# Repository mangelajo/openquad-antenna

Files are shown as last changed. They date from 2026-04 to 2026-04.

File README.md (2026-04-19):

# OpenQuad — Modular Cubical Quad antenna by EA4IPW

Modular and foldable cubical quad antenna design for any HF/VHF/UHF band, built with 3D-printed parts, fiberglass spreaders and an aluminum boom.

<p align="center">
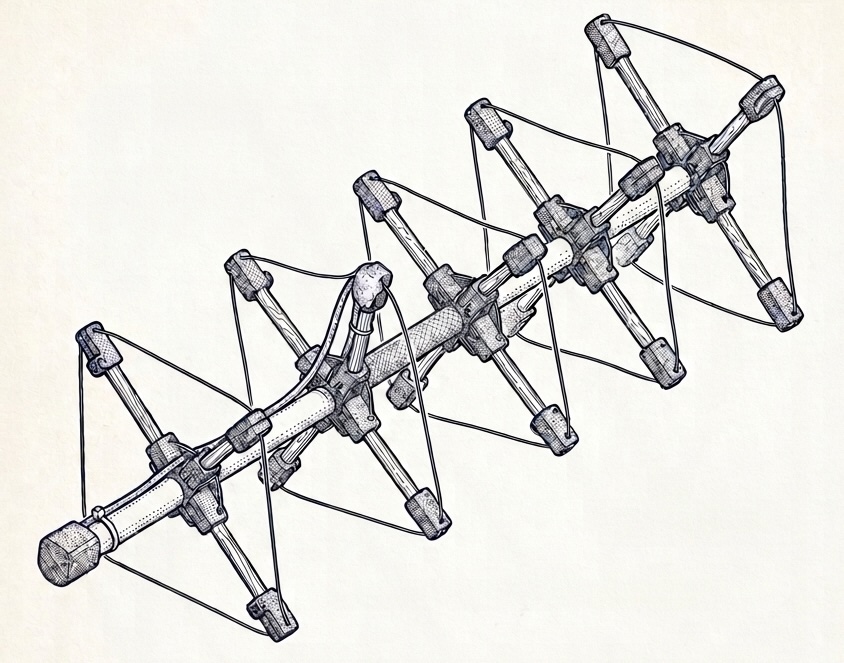
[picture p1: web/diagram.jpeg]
OpenQuad design diagram
  
</p>

## 📖 Construction guide / Guía de construcción

| Language | Build guide | Theory & formulas |
|---|---|---|
| 🇪🇸 Español | [README.es.md](docs/README.es.md) | [TEORIA.es.md](docs/TEORIA.es.md) |
| 🇬🇧 English | [README.en.md](docs/README.en.md) | [TEORIA.en.md](docs/TEORIA.en.md) |
| 🇮🇹 Italiano | [README.it.md](docs/README.it.md) | [TEORIA.it.md](docs/TEORIA.it.md) |
| 🇵🇹 Português | [README.pt.md](docs/README.pt.md) | [TEORIA.pt.md](docs/TEORIA.pt.md) |
| 🇯🇵 日本語 | [README.ja.md](docs/README.ja.md) | [TEORIA.ja.md](docs/TEORIA.ja.md) |
| 🇨🇳 中文 | [README.zh.md](docs/README.zh.md) | [TEORIA.zh.md](docs/TEORIA.zh.md) |

## 🧮 Online calculator

Interactive calculator (6 languages) for sizing the elements, calibrating the velocity factor of your wire, and computing the cut/adjustment needed per element after measuring resonance:

**→ [openquad calculator](web/index.html)** (deployed via GitHub Pages)

## 📁 Repository layout

- [src/](src/) — OpenSCAD parametric models for the 3D-printed clamps and hubs
- [stls/](stls/) — Pre-generated STL files ready to print
- [web/](web/) — HTML/JS calculator (deployed to GitHub Pages)
- `*.md` — Build guide and theory documents in 6 languages

---

*73 de EA4IPW — OpenQuad v1.0*

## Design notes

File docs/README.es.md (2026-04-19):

# OpenQuad — Antena Cubical Quad modular y plegable

**Por EA4IPW — Caso práctico: construcción de un quad de 5 elementos para 435 MHz**

<p align="center">
  Diagrama del diseño
</p>

---

## 1. Qué es este diseño

Este proyecto documenta un **diseño de antena Cubical Quad modular y plegable** pensado para fabricarse con piezas impresas en 3D, varillas de fibra de vidrio o madera como spreaders y un boom de PVC, madera o aluminio.

Las características principales del diseño son:

- **Modular:** cada elemento (reflector, driven, directores) se monta sobre un *bloque* independiente que se desliza y se fija al boom. Puedes construir la antena con 2, 3, 5 , 6, 7 .. elementos usando el mismo hardware.
- **Plegable:** los spreaders pivotan sobre el bloque, de modo que la antena puede recogerse para transporte o almacenamiento y desplegarse en segundos para operar.
- **Escalable por banda:** el diseño paramétrico en OpenSCAD ([src/all_in_one.scad](../src/all_in_one.scad)) permite ajustar el diámetro del boom y de los spreaders y regenerar la pieza para otros tamaños de boom y spreader.

- **Ajustable:** los loops se sujetan con abrazaderas impresas ([stls/regular_wire_clamp.stl](../stls/regular_wire_clamp.stl)) que permiten recortar y volver a fijar el cable durante el tuning.

Esta guía documenta el proceso práctico de construcción y ajuste paso a paso. Los fundamentos teóricos (origen de las fórmulas 1005/1030/975, efecto del velocity factor, rendimiento esperado, referencias bibliográficas) se tratan en un documento separado:

> 📘 **[TEORIA.es.md](TEORIA.es.md) — Fundamentos teóricos y referencias**

Las fórmulas son válidas para cualquier frecuencia; como ejemplo práctico detallado se documenta una construcción real para la banda de 70 cm (435 MHz) con cable de instalación PVC de 0.5 mm².

<p align="center">
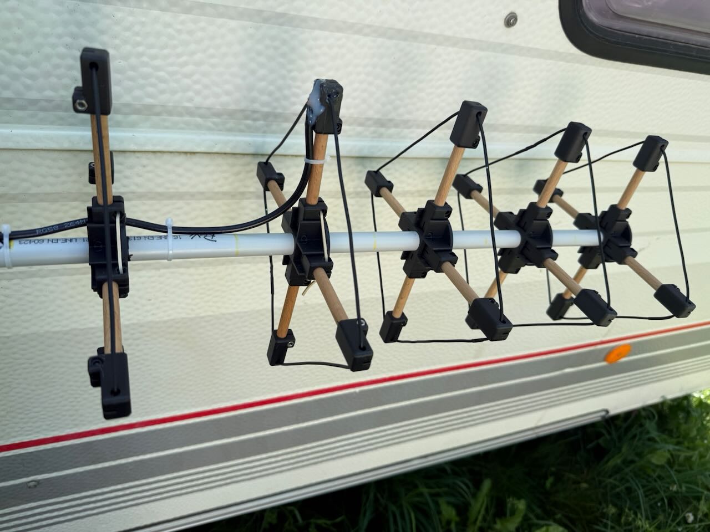
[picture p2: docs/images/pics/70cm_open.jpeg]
Antena desplegada (5 elementos, 435 MHz)
  
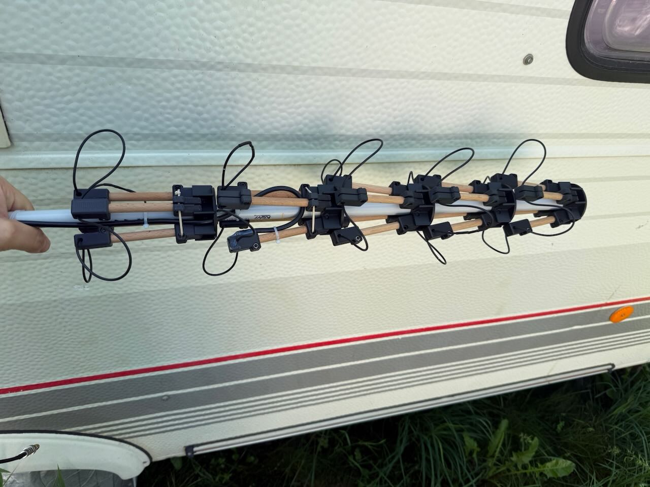
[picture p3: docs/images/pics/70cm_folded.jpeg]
Antena plegada para transporte
  
</p>

---

## 2. Dimensiones para la construcción de referencia (435 MHz, Vf = 0.91)

Las siguientes dimensiones corresponden a la construcción real documentada en esta guía, usando cable PVC de 0.5 mm² con velocity factor medido de 0.91.

> Si construyes para otra frecuencia o con otro tipo de cable, consulta las fórmulas generales y el procedimiento para medir el Vf en [TEORIA.es.md § 2–3](TEORIA.es.md), o usa la [🧮 calculadora online](https://openquad-calc.ea4ipw.es) para obtener las dimensiones directamente.

**Elementos:**

| Elemento | Perímetro (mm) | Perímetro (in) | Lado (mm) | Lado (in) | Spreader (mm) | Spreader (in) |
|---|---|---|---|---|---|---|
| Reflector | 656.8 | 25.86 | 164.2 | 6.46 | 116.1 | 4.57 |
| Driven | 640.8 | 25.23 | 160.2 | 6.31 | 113.3 | 4.46 |
| Director 1 | 621.7 | 24.47 | 155.4 | 6.12 | 109.9 | 4.33 |
| Director 2 | 603.0 | 23.74 | 150.8 | 5.93 | 106.6 | 4.20 |
| Director 3 | 584.9 | 23.03 | 146.2 | 5.76 | 103.4 | 4.07 |
| Director 4 | 567.4 | 22.34 | 141.8 | 5.58 | 100.3 | 3.95 |
| Director 5 | 550.4 | 21.67 | 137.6 | 5.42 | 97.3 | 3.83 |

**Espaciados:**

| Tramo | Distancia (mm) | Distancia (in) |
|---|---|---|
| Reflector → Driven | 137.9 | 5.43 |
| Driven → Director 1 | 103.4 | 4.07 |
| Director → Director | 103.4 | 4.07 |

**Longitud total del boom según configuración:**

| Configuración | Boom (mm) | Boom (in) |
|---|---|---|
| 2 elem (R + DE) | 137.9 | 5.43 |
| 3 elem (R + DE + D1) | 241.4 | 9.50 |
| 4 elem (R + DE + D1 + D2) | 344.8 | 13.57 |
| 5 elem (R + DE + D1–D3) | 448.3 | 17.65 |
| 6 elem (R + DE + D1–D4) | 551.7 | 21.72 |
| 7 elem (R + DE + D1–D5) | 655.2 | 25.80 |

---

## 3. Materiales

Resumen de lo que necesitas para construir la antena. Las secciones siguientes detallan alternativas, dimensionado y justificaciones.

| Material | Especificación recomendada | Cantidad | Subsección |
|---|---|---|---|
| Cable de cobre (elementos) | PVC 0.5 mm² (VHF/UHF); 1–2 mm Ø desnudo o aislado (HF) | Según perímetros (§2) | [3.1](#31-cable-para-los-elementos) |
| Boom | Tubo de aluminio, PVC o madera (cuadrado o circular) | 1, longitud según configuración (§2) | [3.2](#32-boom) |
| Spreaders | Varilla no conductora (fibra de vidrio, haya o PVC), 4–8 mm Ø en VHF/UHF | 4 por elemento | [3.3](#33-spreaders) |
| Tornillos Allen M3 × 12 mm | Hex socket cap (M3×8/M3×10 para spreaders más finos) | 4 por elemento | [3.4](#34-tornillería-y-retención) |
| Tuercas M3 | Hexagonales estándar | 4 por elemento | [3.4](#34-tornillería-y-retención) |
| Goma elástica | Cualquiera que abrace el bloque plegado | 1 por elemento | [3.4](#34-tornillería-y-retención) |
| Coaxial + conector | Según tu equipo (típicamente RG-58/RG-316 en UHF) | 1 | — |
| Termorretráctil | Varios diámetros para aislar soldaduras del feedpoint y empalmes | Unos cm | — |
| Ferritas snap-on mix 43 (opcional, ajuste) | Fair-Rite 0443164251/0443167251 según Ø del coaxial | 5–6 | [4.2](#42-choke-balun-opcional-pero-recomendado-para-la-medida) |

### 3.1. Cable para los elementos

Cualquier cable de cobre con o sin aislamiento sirve. Para cable aislado (PVC, polietileno), recuerda aplicar la corrección de Vf (ver [TEORIA.es.md § 2](TEORIA.es.md)).

En VHF/UHF, secciones de 0.5 mm² a 1.5 mm² funcionan bien. El cable más fino es más manejable; el más grueso mantiene mejor la forma, mi recomendación es el de 0.5mm². A 435 MHz el skin depth es de solo 3 µm, así que toda la corriente fluye por la superficie del conductor. La diferencia de pérdidas entre 0.5 mm² y 1.5 mm² es de ~0.025 dB — completamente despreciable. El ancho de banda se reduce ~8% con el cable más fino, lo que tampoco es significativo en la práctica.

En HF, donde los elementos son mucho más grandes, se usa típicamente cable de cobre de 1–2 mm de diámetro (desnudo o aislado), o incluso cable multifilar para reducir peso.

Para potencias de hasta 50W no hay ningún problema con cable fino. El límite práctico lo ponen las soldaduras y el aislamiento (el PVC se ablanda a ~70°C), no el conductor.

Al unir tramos o cerrar un loop, pela unos 10 mm de cada extremo, únelos en paralelo (trenzando o con un empalme Western Union), suelda con aporte generoso y protege la unión con termorretráctil.

<p align="center">
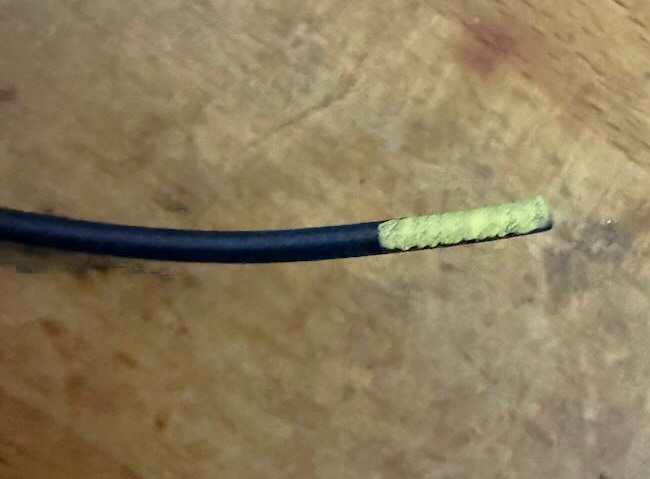
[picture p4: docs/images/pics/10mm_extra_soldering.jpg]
10 mm de cable pelado antes de soldar
  
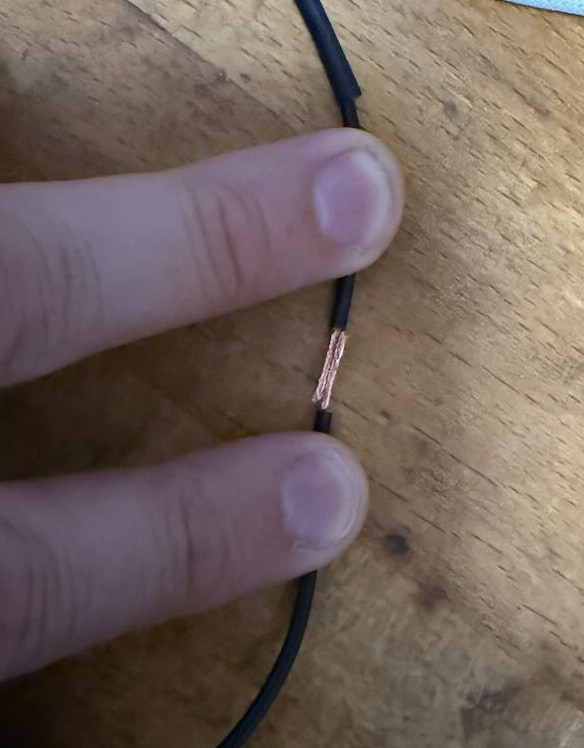
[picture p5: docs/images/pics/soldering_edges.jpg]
Empalme de los dos extremos antes de la soldadura
  
</p>
<p align="center">
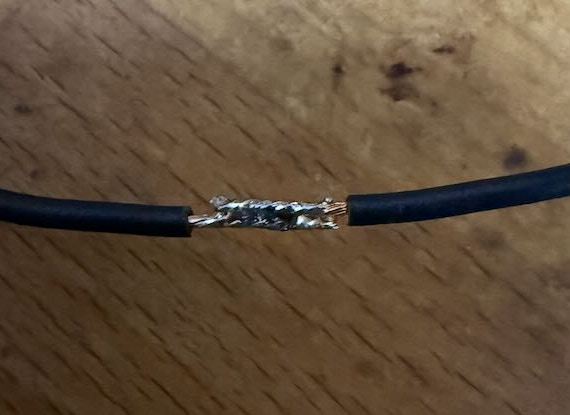
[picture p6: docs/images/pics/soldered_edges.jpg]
Empalme soldado
  
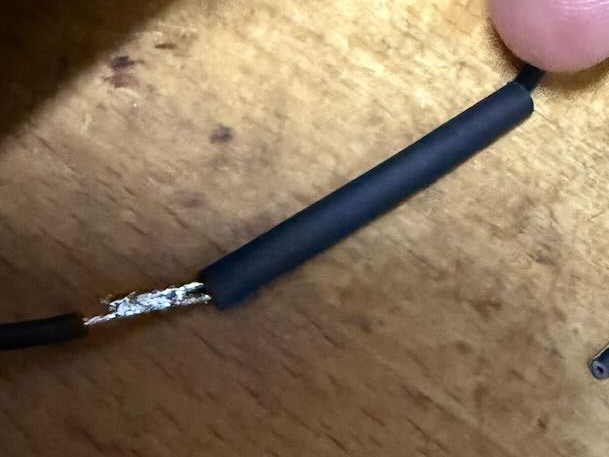
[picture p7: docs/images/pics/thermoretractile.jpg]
Termorretráctil aplicado sobre la soldadura
  
</p>

### 3.2. Boom

El aluminio es ideal: ligero, rígido y fácil de trabajar. Un tubo cuadrado o circular de sección apropiada al tamaño de la antena es suficiente. Para UHF un tubo de PVC también sirve perfectamente.

**¿Afecta un boom metálico a la antena?** En un quad, a diferencia de un Yagi, el boom es perpendicular al plano de los loops y los elementos están separados del boom por los spreaders. El efecto es mínimo o inexistente. **No se necesita corrección de boom** como en un Yagi.

Un boom de madera funciona igual pero es más pesado y absorbe humedad. Su efecto dieléctrico (εr ≈ 2) podría desplazar la frecuencia ~0.1% — irrelevante en la práctica.

Si el boom es circular en vez de cuadrado, no hay diferencia eléctrica. La única consideración es mecánica: asegurar que los hubs de los spreaders queden fijados en la misma orientación angular (ver sección 3.5).

<p align="center">
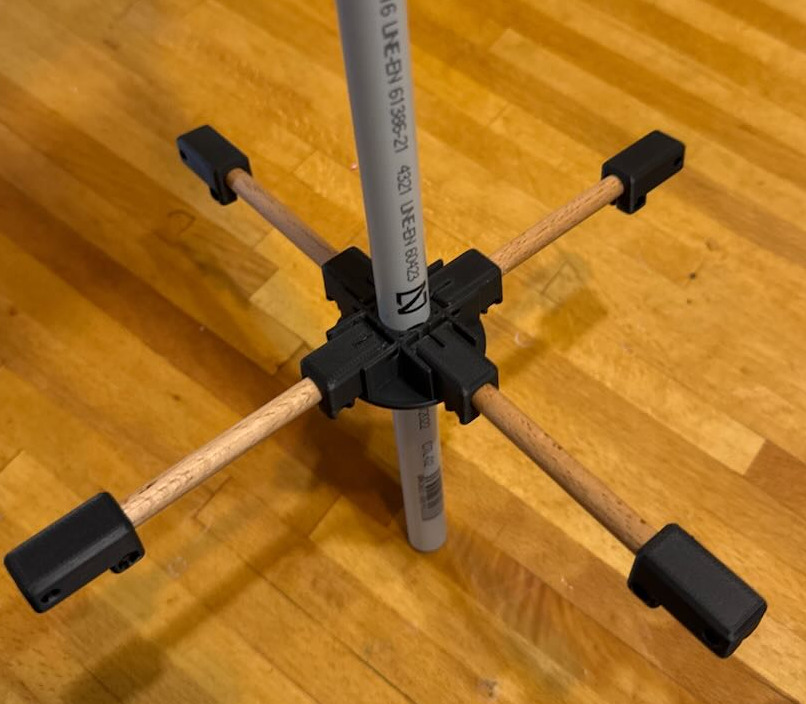
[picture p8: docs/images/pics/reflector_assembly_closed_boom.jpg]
Elemento montado sobre boom de PVC
  
</p>

### 3.3. Spreaders

Varillas de fibra de vidrio, haya, o PVC. Deben ser de material no conductor. El diámetro apropiado depende de la banda: en VHF/UHF, varillas de 4–8 mm son suficientes

<p align="center">
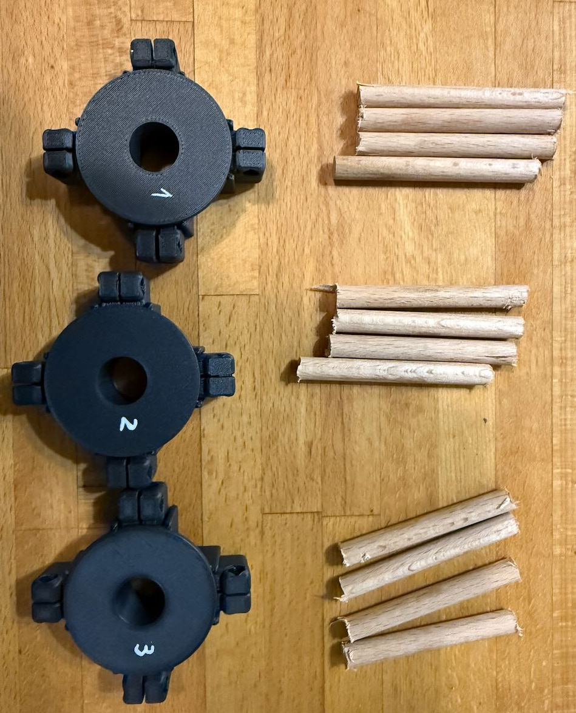
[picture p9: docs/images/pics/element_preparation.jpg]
Hubs impresos y varillas de spreader cortadas a medida
  
</p>

### 3.4. Tornillería y retención

Cada elemento necesita una pequeña cantidad de tornillería estándar para cerrar las abrazaderas sobre los spreaders y mantener el bloque print-in-place plegado durante el transporte:

- **Tornillos Allen (hex socket cap) M3 × 12 mm — 4 por elemento.** Uno por cada abrazadera de spreader; aprietan las dos mitades de la abrazadera alrededor de la varilla. La longitud de 12 mm está dimensionada para un **spreader de 8 mm** — spreaders más finos (4–6 mm) usan un cuerpo de abrazadera más delgado y pueden necesitar un tornillo más corto (M3×8 o M3×10); comprueba la profundidad del canal del tornillo en la pieza renderizada antes de comprar. El alojamiento de la tuerca y la holgura del tornillo están dimensionados para M3 en [src/antenna_spreader_clamp.scad](../src/antenna_spreader_clamp.scad).
- **Tuercas M3 — 4 por elemento.** Se asientan en el hueco hexagonal de cada abrazadera antes de apretar el tornillo.
- **Goma elástica — 1 por elemento.** Envuelve el bloque `all_in_one` plegado para mantener las cuatro abrazaderas cerradas contra el collar del boom durante transporte y almacenamiento.

<p align="center">
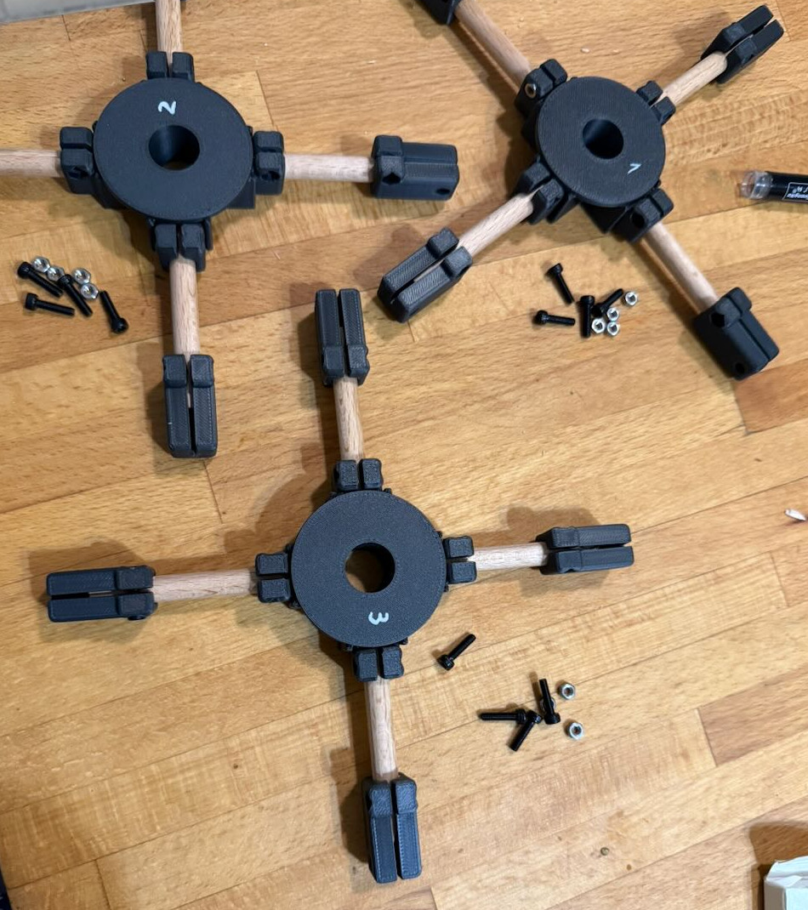
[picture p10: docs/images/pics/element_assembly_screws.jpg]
Bloques montados con tornillería M3
  
</p>

### 3.5. Alineación de los elementos

Todos los loops cuadrados deben estar **alineados en la misma orientación rotacional** sobre el boom. Si se rota un elemento respecto a los demás, el acoplamiento entre elementos se degrada porque los segmentos de corriente dejan de ser paralelos.

- **Unos pocos grados de error:** efecto despreciable.
- **45° de rotación:** acoplamiento seriamente degradado, pérdida de ganancia y F/B.

Con boom cuadrado la alineación es natural. Con boom circular, asegura la orientación con un tornillo prisionero, un pin pasante, o una gota de pegamento.

<p align="center">
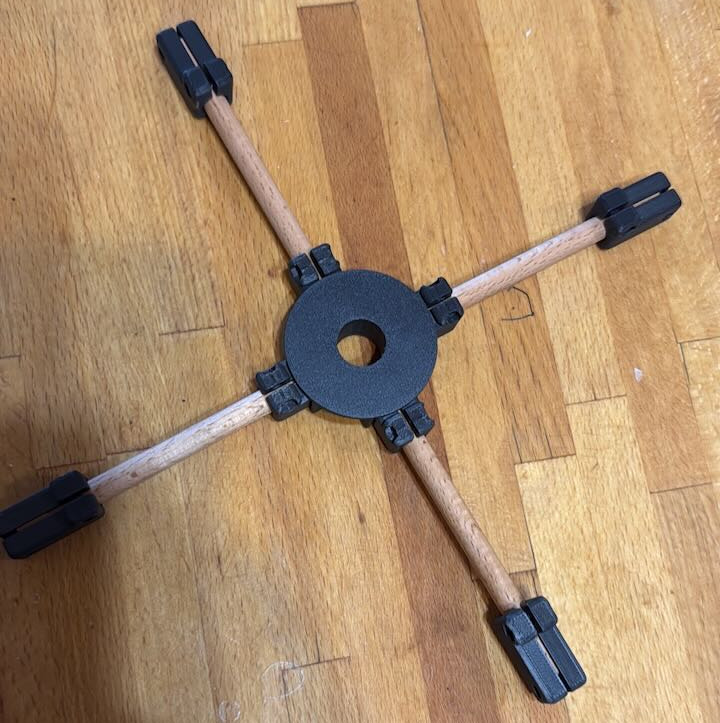
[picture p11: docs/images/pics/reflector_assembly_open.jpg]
Elemento desplegado (spreaders abiertos en X)
  
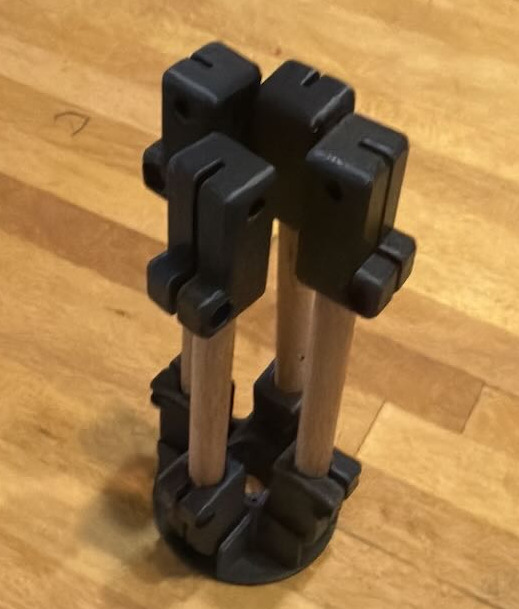
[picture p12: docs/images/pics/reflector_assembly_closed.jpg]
Elemento plegado (spreaders cerrados)
  
</p>

---

## 4. Ajuste paso a paso

### 4.1. Herramientas necesarias

- Analizador de antenas (NanoVNA, LiteVNA, o similar)
- Cable coaxial corto con conector para el VNA
- Soldador y estaño
- Regla milimetrada o calibre digital
- Alicates de corte fino

<p align="center">
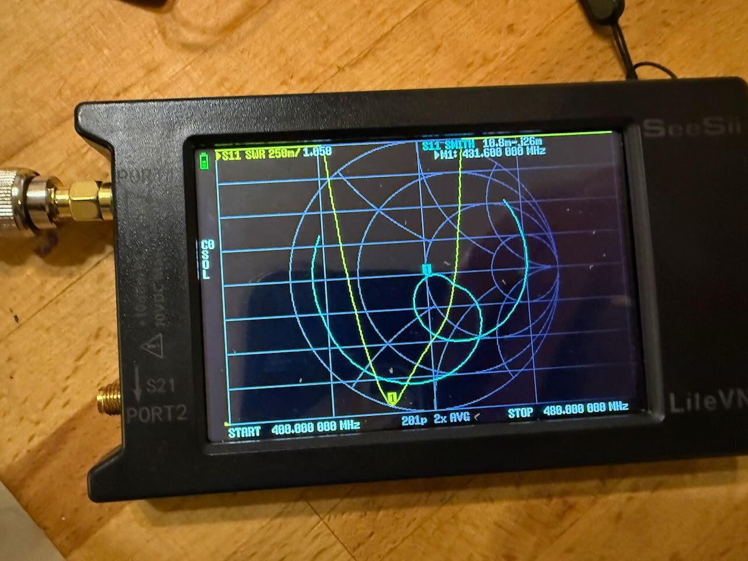
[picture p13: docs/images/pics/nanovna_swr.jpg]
NanoVNA mostrando carta de Smith y SWR de la antena
  
</p>

### 4.2. Choke balun (opcional pero recomendado para la medida)

Un choke balun en el feedpoint mejora la fiabilidad de las medidas al impedir que la trenza del coaxial radie y altere los resultados. Sin choke, tocar o mover el cable del VNA puede cambiar las lecturas.

**Para HF:** un choke bobinado clásico funciona bien: 6–10 vueltas de coaxial sobre un toroide de ferrita (FT-140-43 o similar).

**Para VHF/UHF:** NO uses un choke bobinado — a frecuencias altas la capacitancia entre espiras crea resonancias parásitas. En su lugar, usa **ferritas snap-on (clamp-on)** de mix 43 ensartadas en línea sobre el coaxial justo detrás del feedpoint. 5–6 unidades proporcionan impedancia suficiente.

Referencia de ferritas snap-on válidas para VHF/UHF: Fair-Rite 0443164251 (cable ≤6.6 mm), Fair-Rite 0443167251 (cable ≤9.85 mm), o Fair-Rite 0443164151 (cable ≤12.7 mm), todas en material mix 43. Disponibles en Mouser, DigiKey, o distribuidores similares.

Las snap-on se abren y cierran con los dedos, no requieren herramientas, y son completamente reutilizables.

**Nota:** Muchas antenas comerciales de tipo quad no llevan choke y funcionan perfectamente. El quad tiene una geometría intrínsecamente bien equilibrada en el feedpoint. El choke es principalmente para obtener medidas fiables durante el ajuste, no un requisito para el uso normal.

<p align="center">
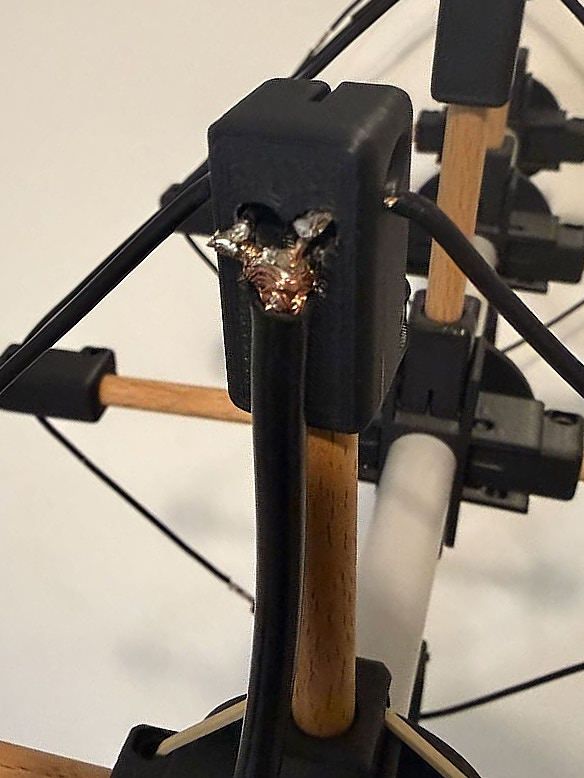
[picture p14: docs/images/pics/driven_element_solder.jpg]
Detalle de la soldadura del driven
  
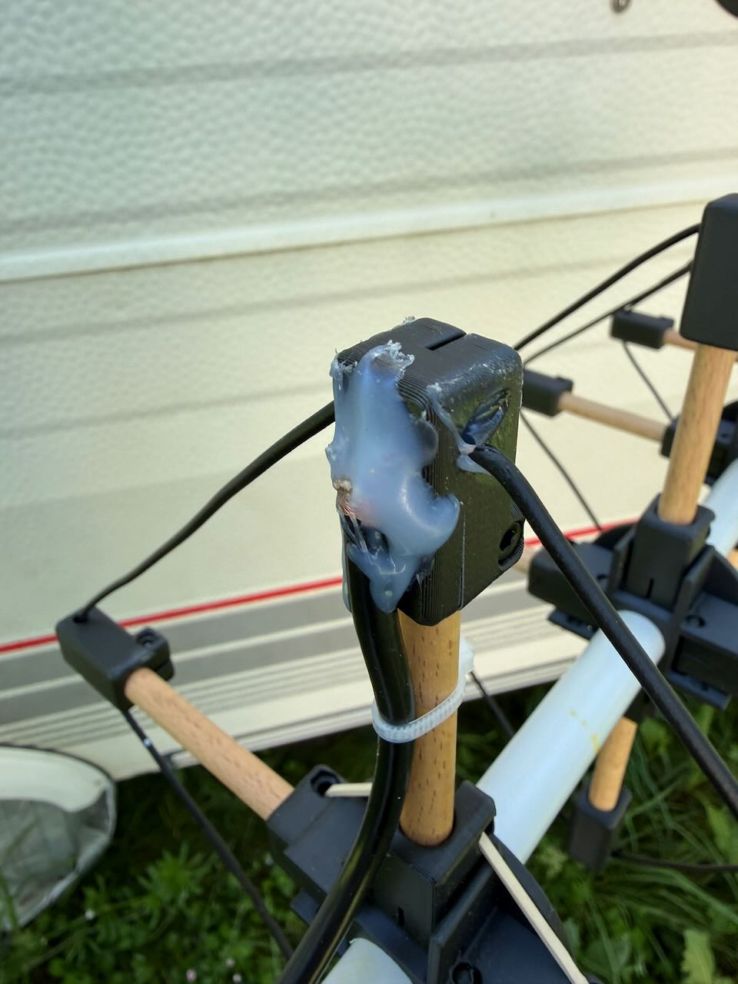
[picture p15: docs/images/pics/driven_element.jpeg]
Driven element con coaxial y sellado
  
</p>

### 4.3. Procedimiento de ajuste

#### Paso 1 — Construir y calibrar el Vf

Todo cable real tiene Vf < 1. El cobre desnudo al aire está alrededor de 0.97 y 0.99, los cables aislados bajan a 0.90–0.97 según el material. El procedimiento recomendado es partir de un valor aproximado y calibrar midiendo:

1. Calcula las dimensiones de todos los elementos con la [🧮 calculadora online](https://openquad-calc.ea4ipw.es) usando como Vf de partida el valor típico de tu cable (0.99 cobre desnudo, ≈0.91 PVC fino, ≈0.95 polietileno, ≈0.97 teflón; tabla completa en [TEORIA.es.md § 2.2](TEORIA.es.md)). La fórmula subyacente es `perímetro = k × λ × Vf`, con `λ = 299,792.458 / f(MHz)` mm y `k_driven ≈ 1.022` (ver [TEORIA.es.md § 1](TEORIA.es.md)).
2. Monta la antena completa con esas dimensiones.
3. Mide la frecuencia resonante del conjunto con el VNA.
4. Introduce la frecuencia medida en la [🧮 calculadora](https://openquad-calc.ea4ipw.es) para obtener el Vf real y las dimensiones corregidas.
5. Acorta cada loop a la nueva medida — las abrazaderas de hilo ([stls/regular_wire_clamp.stl](../stls/regular_wire_clamp.stl)) permiten este ajuste sin rehacer la soldadura.

> Ver [TEORIA.es.md § 2.4](TEORIA.es.md) para más detalles.

**No intentes ajustar el driven aislado a la frecuencia objetivo y luego añadir el reflector esperando que se mantenga.** El acoplamiento siempre desplaza la frecuencia; por eso medimos con la antena completa ya montada.

#### Paso 2 — Añadir los directores, uno a uno

1. Monta el Director 1 a 0.15λ delante del driven. Su perímetro debe ser ~3% menor que el driven.
2. Mide. La frecuencia puede subir o bajar ligeramente dependiendo del acoplamiento.
3. Si el SWR es aceptable, procede al siguiente director.
4. Repite para cada director adicional. Cada uno debe ser un 3% más corto que el anterior.

**Problema común: SWR sube bruscamente al añadir un director.** La causa más frecuente es que el director es demasiado largo (demasiado cerca de la frecuencia de resonancia del driven). Cuando un parásito resuena a la misma frecuencia que el driven, absorbe máxima energía y el SWR se dispara. **Solución:** verifica que el director es realmente un 3% más corto que el driven y recórtalo si es necesario.

#### Paso 3 — Ajuste final

Después de montar todos los elementos, puede ser necesario un retoque fino del driven element para centrar la frecuencia. Los directores raramente necesitan retoque si se cortaron correctamente.

**Tip:** En el VNA, usa la vista de SWR vs frecuencia (no solo la carta de Smith) para ver claramente dónde está el mínimo y el ancho de banda.

<p align="center">
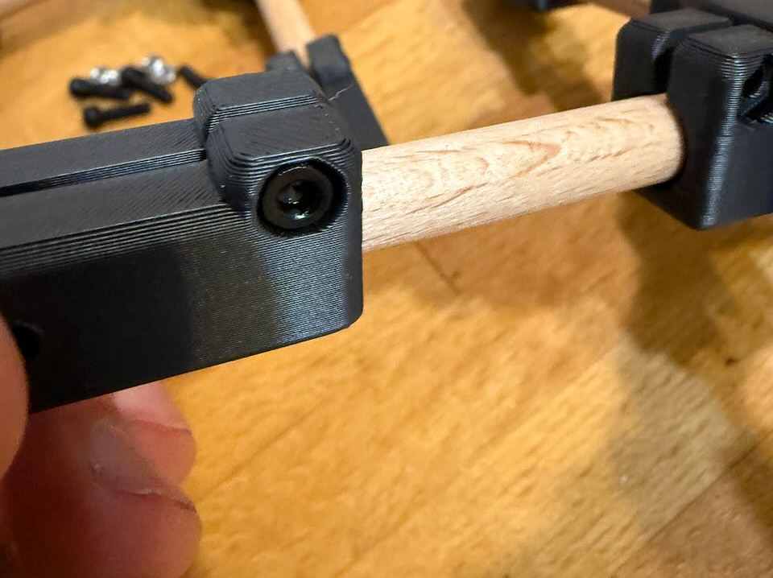
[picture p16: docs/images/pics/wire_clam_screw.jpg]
Abrazadera de hilo — lado del tornillo Allen
  
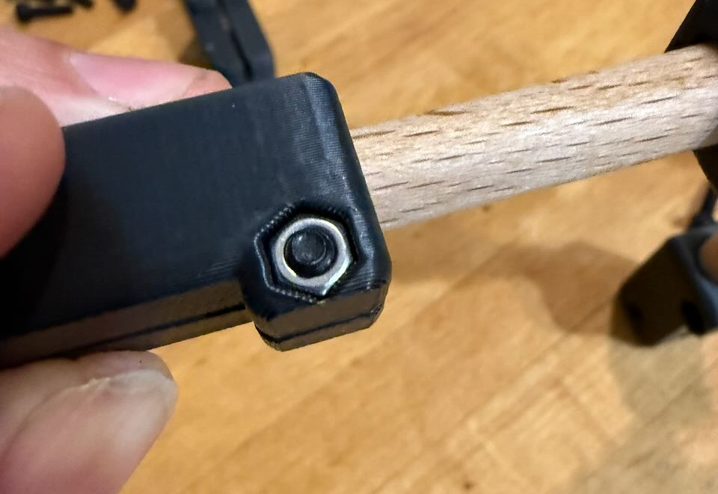
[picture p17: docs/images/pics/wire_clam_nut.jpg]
Abrazadera de hilo — lado de la tuerca
  
</p>

---

## 5. Problemas frecuentes y soluciones

### La frecuencia de resonancia está muy por debajo de lo esperado

**Causa probable:** no se ha tenido en cuenta el Vf del cable aislado. Un cable PVC puede tener Vf = 0.91–0.95, lo que alarga eléctricamente los elementos.

**Solución:** mide el Vf empíricamente (paso 1 del procedimiento) y recalcula las dimensiones.

### El SWR sube mucho al añadir un director

**Causa probable:** el director está cortado a la misma longitud que el driven, o muy cerca. Cuando un parásito resuena en la misma frecuencia que el driven, absorbe máxima energía.

**Solución:** verifica que el director es un 3% más corto que el driven. Recórtalo si es necesario.

### La frecuencia baja al añadir el reflector

**Causa:** acoplamiento mutuo inductivo entre reflector y driven. Es comportamiento normal, no un error.

**Solución:** precompensar el driven (ajustarlo solo a una frecuencia más alta de la objetivo) o ajustar con driven + reflector montados conjuntamente.

### La frecuencia se desplaza al manipular la antena

**Causa:** en VHF/UHF, 1–2 mm de desplazamiento en una esquina cambian la frecuencia fácilmente.

**Solución:** asegura bien los cables en los spreaders antes de las medidas definitivas, ajustando la tensión para que que el cable se mantenga estirado.

### Las medidas del VNA cambian al tocar el cable

**Causa:** corriente de modo común en la trenza exterior del coaxial. El cable del VNA se comporta como parte de la antena.

**Solución:** añade ferritas snap-on (mix 43) en el feedpoint. Si no tienes ferritas, al menos mantén la misma disposición del cable entre medidas.

### El SWR es bueno pero el F/B es pobre

**Causa probable:** el reflector no está bien ajustado. El SWR y el F/B se optimizan a diferentes longitudes del reflector.

**Solución:** prueba a alargar o acortar el reflector 1–2%. Alternativamente, usa un stub cortocircuitado en el reflector para ajustarlo sin cambiar su longitud física.

---

## 6. Resultado de la construcción de referencia

La antena documentada como ejemplo en esta guía (5 elementos, 435 MHz, cable PVC de 0.5 mm², Vf medido de 0.91) alcanzó los siguientes resultados medidos:

- **SWR:** 1.1 en el punto de mínimo (432 MHz), <1.6 a 435 MHz
- **F/B medido:** ~6 unidades S de diferencia (S9 frontal, S3 trasero) ≈ 30–36 dB
- **Impedancia en resonancia:** próxima a 50 Ω
- **Ancho de banda útil (SWR < 2):** ~430–440 MHz

> Para comparar con los valores teóricos esperados en otras configuraciones (2–7 elementos) y la equivalencia con Yagi, ver [TEORIA.es.md § 4](TEORIA.es.md).

<p align="center">
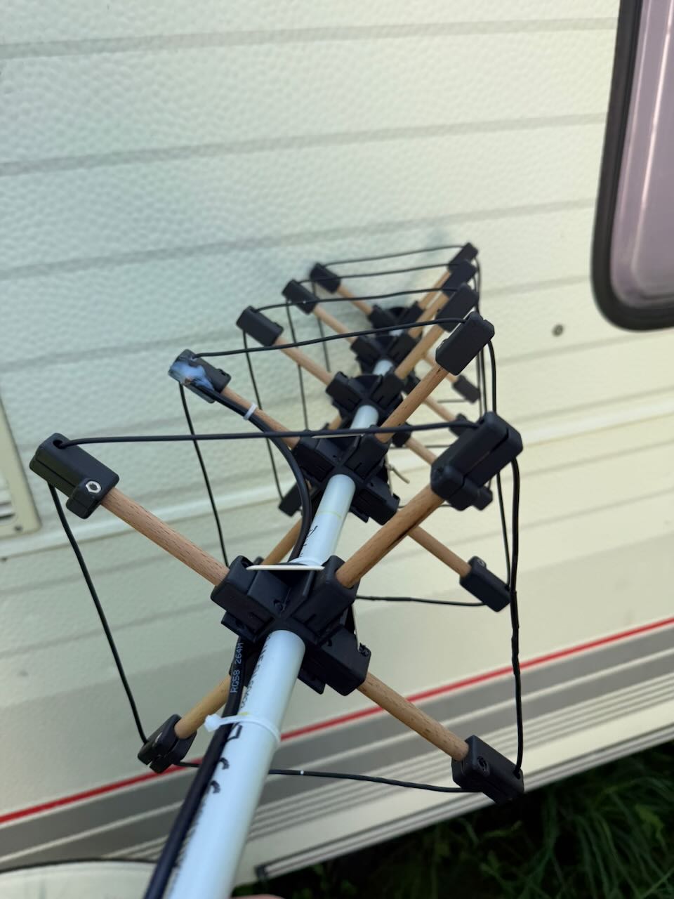
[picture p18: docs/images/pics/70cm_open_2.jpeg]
Vista 3/4 de la antena de 5 elementos para 435 MHz construida
  
</p>

---

## 7. Piezas pre-construidas

CI publica un conjunto pre-renderizado de STL para los tamaños de boom y spreader más comunes en cada release. Cada combinación se distribuye como un único zip que contiene las tres piezas imprimibles (`all_in_one`, `driven_element`, `regular_wire_clamp`) más las vistas previas en PNG. Descarga la combinación que coincida con tu hardware y empieza a imprimir — no hace falta OpenSCAD.

Si ninguna de las combinaciones pre-renderizadas coincide con tu hardware, consulta el [§ 7.4](#74-construir-un-tamaño-personalizado) más abajo para renderizar la tuya.

### 7.1. Bloque todo-en-uno (collar del boom + 4 abrazaderas)

<p align="center">
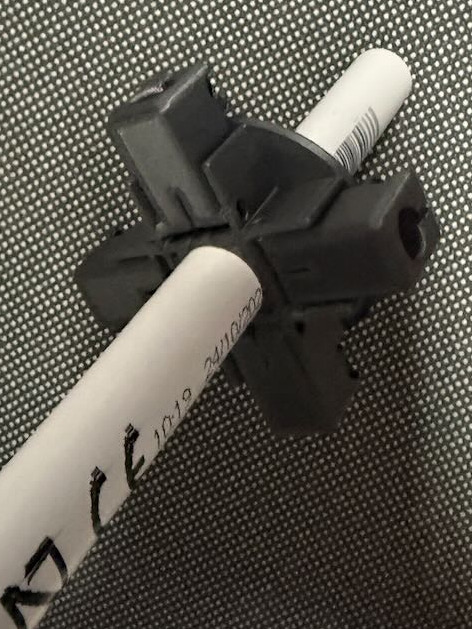
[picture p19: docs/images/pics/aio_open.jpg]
Bloque all-in-one con las abrazaderas abiertas
  
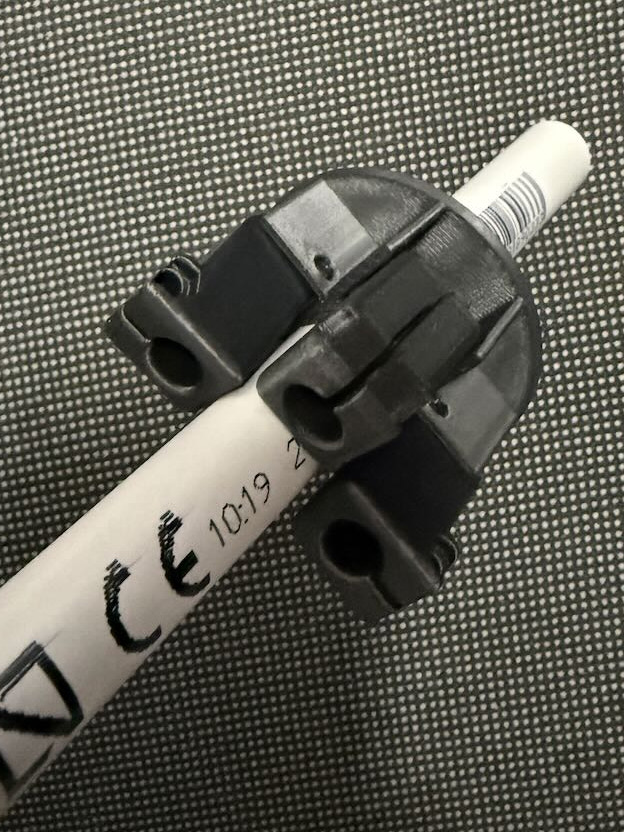
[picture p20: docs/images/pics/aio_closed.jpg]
Bloque all-in-one con las abrazaderas cerradas contra el collar del boom
  
</p>

Forma del boom × dimensión del boom en filas, diámetro del spreader en columnas.

| Boom \ Spreader | 4.05 mm | 6.07 mm | 8.10 mm |
|---|---|---|---|
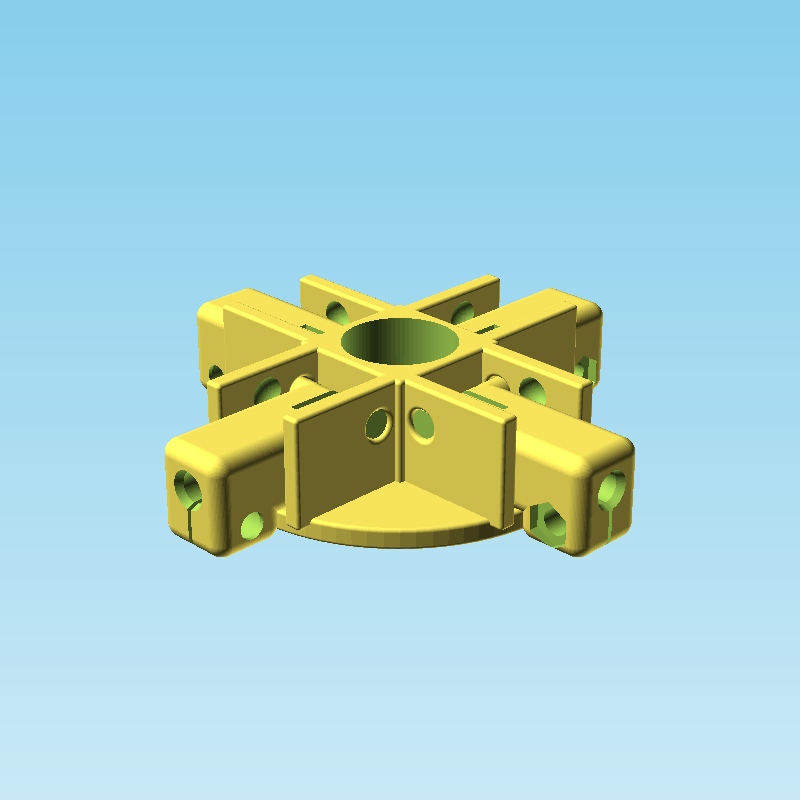
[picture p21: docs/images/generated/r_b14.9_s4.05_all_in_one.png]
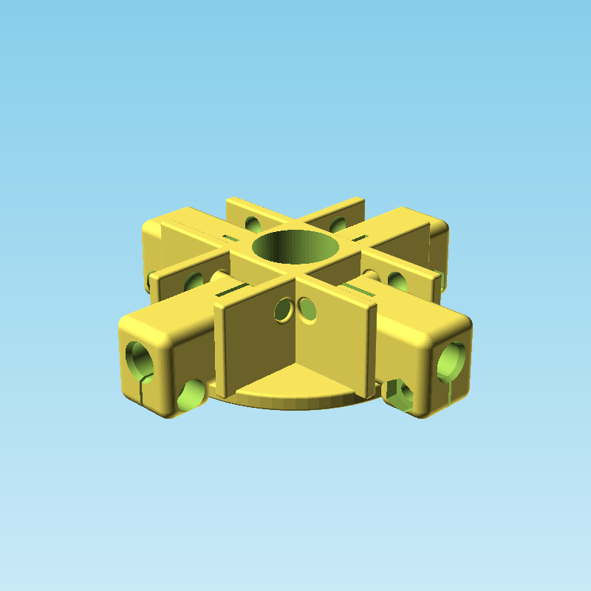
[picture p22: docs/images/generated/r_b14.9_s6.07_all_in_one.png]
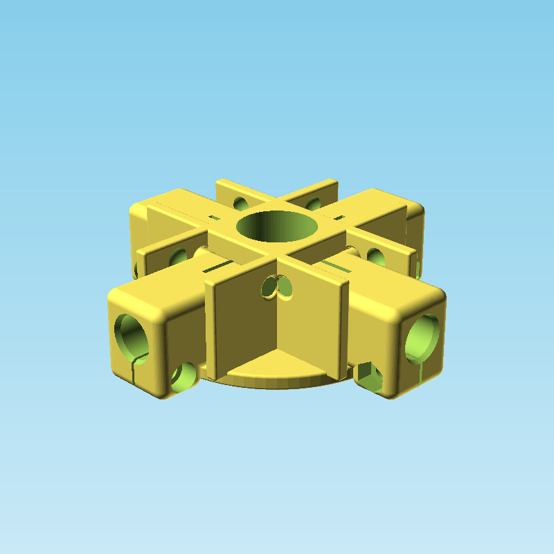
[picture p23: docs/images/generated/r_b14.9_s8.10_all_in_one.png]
| **Redondo 14.9 mm** |  |  |  |
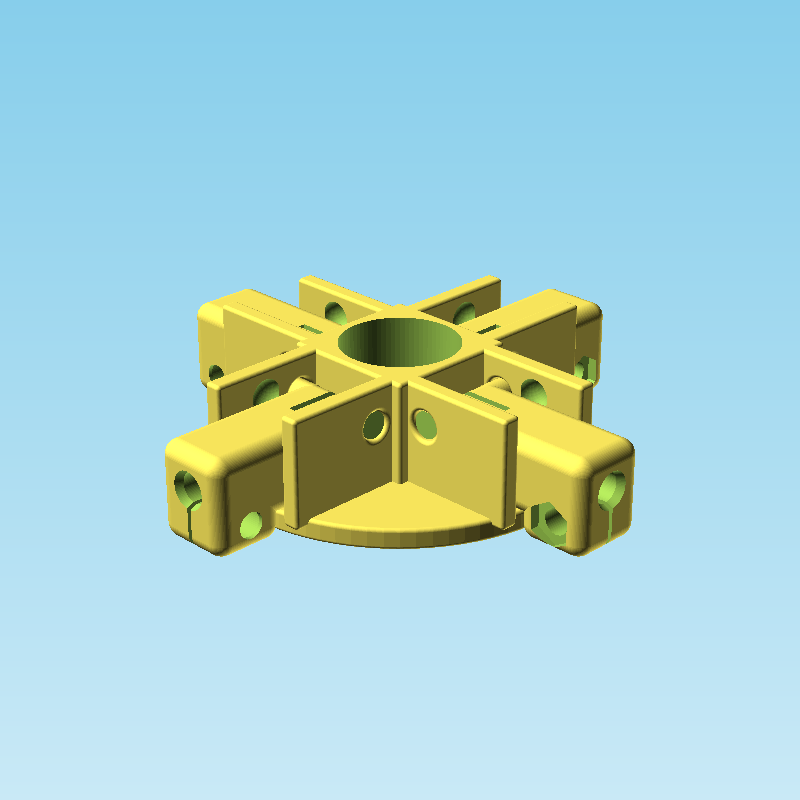
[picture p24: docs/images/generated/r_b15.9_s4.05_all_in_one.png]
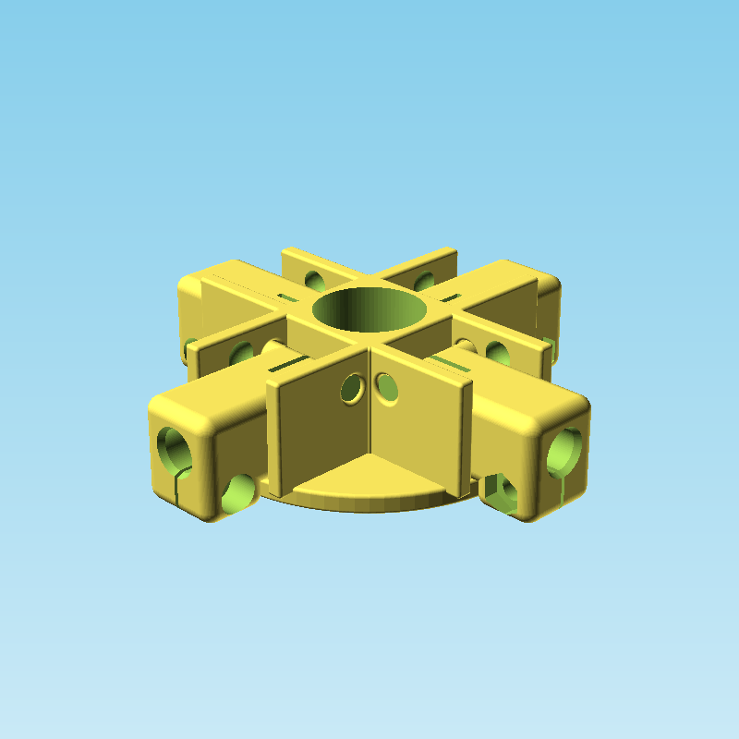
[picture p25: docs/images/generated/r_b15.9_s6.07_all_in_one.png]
| **Redondo 15.9 mm** |  |  |  |
| **Redondo 19.9 mm** |  |  |  |
| **Cuadrado 14.9 mm** |  |  |  |
| **Cuadrado 15.9 mm** |  |  |  |
| **Cuadrado 19.9 mm** |  |  |  |

### 7.2. Abrazaderas de spreader

Estas dos piezas dependen únicamente del diámetro del spreader (la forma y dimensión del boom no importan), por lo que solo hay tres variantes de cada una.

| Spreader | Elemento excitado | Abrazadera de hilo (parásito) |
|---|---|---|
| **4.05 mm** |  |  |
| **6.07 mm** |  |  |
| **8.10 mm** |  |  |

### 7.3. Descargas

Cada enlace es un zip con los tres STL más las vistas previas PNG para esa combinación. Siempre apunta a la **última release**.

| Boom \ Spreader | 4.05 mm | 6.07 mm | 8.10 mm |
|---|---|---|---|
| **Redondo 14.9 mm** | [zip](https://github.com/mangelajo/openquad-antenna/releases/latest/download/round_boom_14.9mm_spreaders_4.05mm.zip) | [zip](https://github.com/mangelajo/openquad-antenna/releases/latest/download/round_boom_14.9mm_spreaders_6.07mm.zip) | [zip](https://github.com/mangelajo/openquad-antenna/releases/latest/download/round_boom_14.9mm_spreaders_8.10mm.zip) |
| **Redondo 15.9 mm** | [zip](https://github.com/mangelajo/openquad-antenna/releases/latest/download/round_boom_15.9mm_spreaders_4.05mm.zip) | [zip](https://github.com/mangelajo/openquad-antenna/releases/latest/download/round_boom_15.9mm_spreaders_6.07mm.zip) | [zip](https://github.com/mangelajo/openquad-antenna/releases/latest/download/round_boom_15.9mm_spreaders_8.10mm.zip) |
| **Redondo 19.9 mm** | [zip](https://github.com/mangelajo/openquad-antenna/releases/latest/download/round_boom_19.9mm_spreaders_4.05mm.zip) | [zip](https://github.com/mangelajo/openquad-antenna/releases/latest/download/round_boom_19.9mm_spreaders_6.07mm.zip) | [zip](https://github.com/mangelajo/openquad-antenna/releases/latest/download/round_boom_19.9mm_spreaders_8.10mm.zip) |
| **Cuadrado 14.9 mm** | [zip](https://github.com/mangelajo/openquad-antenna/releases/latest/download/square_boom_14.9mm_spreaders_4.05mm.zip) | [zip](https://github.com/mangelajo/openquad-antenna/releases/latest/download/square_boom_14.9mm_spreaders_6.07mm.zip) | [zip](https://github.com/mangelajo/openquad-antenna/releases/latest/download/square_boom_14.9mm_spreaders_8.10mm.zip) |
| **Cuadrado 15.9 mm** | [zip](https://github.com/mangelajo/openquad-antenna/releases/latest/download/square_boom_15.9mm_spreaders_4.05mm.zip) | [zip](https://github.com/mangelajo/openquad-antenna/releases/latest/download/square_boom_15.9mm_spreaders_6.07mm.zip) | [zip](https://github.com/mangelajo/openquad-antenna/releases/latest/download/square_boom_15.9mm_spreaders_8.10mm.zip) |
| **Cuadrado 19.9 mm** | [zip](https://github.com/mangelajo/openquad-antenna/releases/latest/download/square_boom_19.9mm_spreaders_4.05mm.zip) | [zip](https://github.com/mangelajo/openquad-antenna/releases/latest/download/square_boom_19.9mm_spreaders_6.07mm.zip) | [zip](https://github.com/mangelajo/openquad-antenna/releases/latest/download/square_boom_19.9mm_spreaders_8.10mm.zip) |

### 7.4. Construir un tamaño personalizado

Si ninguna de las combinaciones pre-renderizadas coincide con tu hardware (o quieres experimentar con otros diámetros), puedes renderizar las piezas tú mismo. Hay tres parámetros que normalmente tocarás, todos en el archivo [src/all_in_one.scad](../src/all_in_one.scad):

- `boom_is_round` — `true` para tubo redondo, `false` para cuadrado.
- `boom_dia` (redondo) **o** `boom_side` (cuadrado) — dimensión exterior del boom en mm.
- `spreaders_dia` — diámetro exterior de tu varilla spreader en mm.

El elemento excitado y la abrazadera de hilo regular ([src/antenna_spreader_clamp.scad](../src/antenna_spreader_clamp.scad)) solo dependen de `spreaders_dia` y de `driven_element` (`true` / `false`).

> ⚠️ **Pre-verifica visualmente el todo-en-uno antes de laminar — especialmente los pivotes.** Esta pieza es print-in-place: las cuatro abrazaderas se imprimen ya unidas al collar central mediante cilindros de pivote finos, con pequeñas esferas de retención (lock-detent) que mantienen cada abrazadera abierta (para imprimir) o plegada (para transporte). Tamaños inusuales de boom o spreader pueden desplazar la geometría lo suficiente como para fusionar los pivotes sólidos (la abrazadera no pivota) o abrirlos demasiado (la retención no engancha). Renderiza siempre el modelo con **F6** en OpenSCAD, haz zoom en uno de los pivotes y confirma:
>
> - El cilindro del pivote tiene un anillo claro de holgura a su alrededor dentro del agujero — sin paredes fusionadas.
> - Las esferas de la retención son visibles como elementos distintos, no fusionadas con el material circundante.
> - El cuerpo de la abrazadera mantiene una separación continua con las placas del marco del pivote.
>
> Si algo parece fusionado o de espesor cero, los valores a ajustar son `print_gap` y `pivot_clearance` (en la sección *Hidden* cerca del inicio de [src/all_in_one.scad](../src/all_in_one.scad)).

**Opción A — GUI de OpenSCAD**

1. Instala OpenSCAD (descarga una versión **nightly 2026.x** reciente desde <https://openscad.org/downloads.html> — la versión estable 2021.01 no incluye el backend manifold que se usa aquí).
2. Abre [src/all_in_one.scad](../src/all_in_one.scad). El panel Customizer de la derecha solo expone los cuatro parámetros de boom/spreader anteriores (el resto de los parámetros del modelo están ocultos a propósito).
3. Edita los valores, pulsa **F5** para una vista previa rápida y luego **F6** (el icono del reloj) para renderizar la geometría completa.
4. Inspecciona (especialmente los pivotes — ver aviso arriba) y luego **Archivo → Exportar → Exportar como STL…**.
5. Repite con [src/antenna_spreader_clamp.scad](../src/antenna_spreader_clamp.scad) para `driven_element=true` y `driven_element=false`.

**Opción B — CLI / Makefile**

El repositorio incluye un [Makefile](../Makefile) que envuelve la CLI de OpenSCAD. Requiere `openscad` en tu `PATH` (o pasar `OPENSCAD=/ruta/a/openscad`).

La forma más simple: edita los valores por defecto de `boom_…` / `spreaders_dia` al principio de [src/all_in_one.scad](../src/all_in_one.scad), luego:

```bash
make            # construye build/all_in_one.stl, build/driven_element.stl, build/regular_wire_clamp.stl
make renders    # también genera vistas previas PNG de 800×800
```

O llama a OpenSCAD directamente con sobrecargas `-D`, dejando los archivos fuente intactos:

```bash
openscad --backend=manifold -o my_block.stl \
  -D 'boom_is_round=true' -D 'boom_dia=22.0' -D 'spreaders_dia=5.0' \
  src/all_in_one.scad

openscad --backend=manifold -o driven.stl \
  -D 'driven_element=true' -D 'spreaders_dia=5.0' \
  src/antenna_spreader_clamp.scad

openscad --backend=manifold -o wire_clamp.stl \
  -D 'driven_element=false' -D 'spreaders_dia=5.0' \
  src/antenna_spreader_clamp.scad
```

Ejecuta `make help` para ver todos los targets disponibles (`all`, `matrix`, `zip`, `renders`, `docs-images`, `clean`).

---

*73 de EA4IPW — OpenQuad v1.0*

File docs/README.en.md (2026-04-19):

# OpenQuad — Modular and foldable Cubical Quad antenna

**By EA4IPW — Reference build: a 5-element quad for 435 MHz**

<p align="center">
  Design diagram
</p>

---

## 1. What this design is

This project documents a **modular and foldable Cubical Quad antenna design** intended to be built with 3D-printed parts, fiberglass or wooden rods as spreaders, and a PVC, wooden or aluminum boom.

The main features of the design are:

- **Modular:** each element (reflector, driven, directors) is mounted on an independent *block* that slides onto and clamps to the boom. You can build the antenna with 2, 3, 5, 6, 7 .. elements using the same hardware.
- **Foldable:** the spreaders pivot on the block, so the antenna can be collapsed for transport or storage and deployed in seconds for operation.
- **Scalable per band:** the parametric OpenSCAD design ([src/all_in_one.scad](../src/all_in_one.scad)) lets you adjust the boom and spreader diameters and regenerate the part for other boom and spreader sizes.

- **Adjustable:** the loops are held with printed clamps ([stls/regular_wire_clamp.stl](../stls/regular_wire_clamp.stl)) that allow you to trim and re-clamp the wire during tuning.

This guide documents the practical construction and tuning process step by step. The theoretical foundations (origin of the 1005/1030/975 formulas, effect of velocity factor, expected performance, bibliographic references) are covered in a separate document:

> 📘 **[TEORIA.en.md](TEORIA.en.md) — Theoretical foundations and references**

The formulas are valid for any frequency; as a detailed practical example, a real build for the 70 cm band (435 MHz) with 0.5 mm² PVC installation wire is documented.

<p align="center">
  Deployed antenna (5 elements, 435 MHz)
  Antenna folded for transport
</p>

---

## 2. Dimensions for the reference build (435 MHz, Vf = 0.91)

The following dimensions correspond to the real build documented in this guide, using 0.5 mm² PVC wire with a measured velocity factor of 0.91.

> If you build for another frequency or with a different type of wire, see the general formulas and the procedure for measuring Vf in [TEORIA.en.md § 2–3](TEORIA.en.md), or use the [🧮 online calculator](https://openquad-calc.ea4ipw.es) to get the dimensions directly.

**Elements:**

| Element | Perimeter (mm) | Perimeter (in) | Side (mm) | Side (in) | Spreader (mm) | Spreader (in) |
|---|---|---|---|---|---|---|
| Reflector | 656.8 | 25.86 | 164.2 | 6.46 | 116.1 | 4.57 |
| Driven | 640.8 | 25.23 | 160.2 | 6.31 | 113.3 | 4.46 |
| Director 1 | 621.7 | 24.47 | 155.4 | 6.12 | 109.9 | 4.33 |
| Director 2 | 603.0 | 23.74 | 150.8 | 5.93 | 106.6 | 4.20 |
| Director 3 | 584.9 | 23.03 | 146.2 | 5.76 | 103.4 | 4.07 |
| Director 4 | 567.4 | 22.34 | 141.8 | 5.58 | 100.3 | 3.95 |
| Director 5 | 550.4 | 21.67 | 137.6 | 5.42 | 97.3 | 3.83 |

**Spacings:**

| Segment | Distance (mm) | Distance (in) |
|---|---|---|
| Reflector → Driven | 137.9 | 5.43 |
| Driven → Director 1 | 103.4 | 4.07 |
| Director → Director | 103.4 | 4.07 |

**Total boom length by configuration:**

| Configuration | Boom (mm) | Boom (in) |
|---|---|---|
| 2 elem (R + DE) | 137.9 | 5.43 |
| 3 elem (R + DE + D1) | 241.4 | 9.50 |
| 4 elem (R + DE + D1 + D2) | 344.8 | 13.57 |
| 5 elem (R + DE + D1–D3) | 448.3 | 17.65 |
| 6 elem (R + DE + D1–D4) | 551.7 | 21.72 |
| 7 elem (R + DE + D1–D5) | 655.2 | 25.80 |

---

## 3. Materials

A summary of what you need to build the antenna. The sections below detail alternatives, sizing and rationale.

| Material | Recommended specification | Quantity | Subsection |
|---|---|---|---|
| Copper wire (elements) | PVC 0.5 mm² (VHF/UHF); 1–2 mm Ø bare or insulated (HF) | According to perimeters (§2) | [3.1](#31-wire-for-the-elements) |
| Boom | Aluminum, PVC or wooden tube (square or circular) | 1, length per configuration (§2) | [3.2](#32-boom) |
| Spreaders | Non-conductive rod (fiberglass, beech or PVC), 4–8 mm Ø at VHF/UHF | 4 per element | [3.3](#33-spreaders) |
| M3 × 12 mm hex socket cap screws | Hex socket cap (M3×8/M3×10 for thinner spreaders) | 4 per element | [3.4](#34-fasteners-and-retention) |
| M3 nuts | Standard hex | 4 per element | [3.4](#34-fasteners-and-retention) |
| Rubber band | Any that fits around the folded block | 1 per element | [3.4](#34-fasteners-and-retention) |
| Coax + connector | According to your rig (typically RG-58/RG-316 at UHF) | 1 | — |
| Heat-shrink tubing | Various diameters to insulate feedpoint solder joints and splices | A few cm | — |
| Snap-on ferrites mix 43 (optional, tuning) | Fair-Rite 0443164251/0443167251 by coax Ø | 5–6 | [4.2](#42-choke-balun-optional-but-recommended-for-measurement) |

### 3.1. Wire for the elements

Any copper wire, with or without insulation, works. For insulated wire (PVC, polyethylene), remember to apply the Vf correction (see [TEORIA.en.md § 2](TEORIA.en.md)).

At VHF/UHF, sections from 0.5 mm² to 1.5 mm² work well. Thinner wire is easier to handle; thicker wire holds its shape better. My recommendation is 0.5 mm². At 435 MHz the skin depth is only 3 µm, so all the current flows along the surface of the conductor. The loss difference between 0.5 mm² and 1.5 mm² is ~0.025 dB — completely negligible. Bandwidth is reduced by ~8% with thinner wire, which is not significant in practice either.

At HF, where the elements are much larger, copper wire of 1–2 mm diameter (bare or insulated) is typically used, or even stranded wire to reduce weight.

For powers up to 50W there is no problem with thin wire. The practical limit is set by the solder joints and the insulation (PVC softens at ~70°C), not by the conductor.

When splicing lengths or closing a loop, strip about 10 mm from each end, join them in parallel (by twisting or with a Western Union splice), solder generously, and protect the joint with heat-shrink tubing.

<p align="center">
  10 mm of stripped wire before soldering
  Splice of the two ends before soldering
</p>
<p align="center">
  Soldered splice
  Heat-shrink applied over the solder joint
</p>

### 3.2. Boom

Aluminum is ideal: light, stiff and easy to work with. A square or circular tube of a cross-section appropriate to the size of the antenna is sufficient. For UHF, a PVC tube also works perfectly.

**Does a metal boom affect the antenna?** In a quad, unlike a Yagi, the boom is perpendicular to the plane of the loops and the elements are separated from the boom by the spreaders. The effect is minimal or non-existent. **No boom correction is needed** as in a Yagi.

A wooden boom works the same but is heavier and absorbs moisture. Its dielectric effect (εr ≈ 2) could shift the frequency by ~0.1% — irrelevant in practice.

If the boom is circular instead of square, there is no electrical difference. The only consideration is mechanical: making sure the spreader hubs are fixed in the same angular orientation (see section 3.5).

<p align="center">
  Element mounted on a PVC boom
</p>

### 3.3. Spreaders

Fiberglass, beech or PVC rods. They must be made of a non-conductive material. The appropriate diameter depends on the band: at VHF/UHF, 4–8 mm rods are sufficient.

<p align="center">
  Printed hubs and cut spreader rods ready to assemble
</p>

### 3.4. Fasteners and retention

Each element needs a small amount of standard hardware to close the clamps onto the spreaders and keep the print-in-place block folded during transport:

- **M3 × 12 mm hex socket cap screws — 4 per element.** One per spreader clamp; they pull the clamp halves together around the spreader rod. The 12 mm length is sized for an **8 mm spreader** — thinner spreaders (4–6 mm) use a thinner clamp body and may need a shorter screw (M3×8 or M3×10); check the depth of the screw channel on the rendered part before buying. The nut seat and screw clearance are dimensioned for M3 in [src/antenna_spreader_clamp.scad](../src/antenna_spreader_clamp.scad).
- **M3 nuts — 4 per element.** Seat into the hex pocket on each clamp before tightening the screw.
- **Rubber band — 1 per element.** Wraps around the folded `all_in_one` block to keep the four clamps closed against the boom collar during transport and storage.

<p align="center">
  Assembled blocks with M3 hardware
</p>

### 3.5. Element alignment

All the square loops must be **aligned in the same rotational orientation** on the boom. If one element is rotated with respect to the others, the coupling between elements degrades because the current segments are no longer parallel.

- **A few degrees of error:** negligible effect.
- **45° rotation:** seriously degraded coupling, loss of gain and F/B.

With a square boom, alignment is natural. With a circular boom, ensure orientation with a set screw, a through pin, or a drop of glue.

<p align="center">
  Element deployed (spreaders open in X)
  Element folded (spreaders closed)
</p>

---

## 4. Step-by-step tuning

### 4.1. Tools needed

- Antenna analyzer (NanoVNA, LiteVNA, or similar)
- Short coaxial cable with connector for the VNA
- Soldering iron and solder
- Millimeter ruler or digital caliper
- Fine cutting pliers

<p align="center">
  NanoVNA showing the Smith chart and SWR of the antenna
</p>

### 4.2. Choke balun (optional but recommended for measurement)

A choke balun at the feedpoint improves the reliability of the measurements by preventing the coax braid from radiating and altering the results. Without a choke, touching or moving the VNA cable can change the readings.

**For HF:** a classic wound choke works well: 6–10 turns of coax on a ferrite toroid (FT-140-43 or similar).

**For VHF/UHF:** do NOT use a wound choke — at high frequencies the capacitance between turns creates parasitic resonances. Instead, use **snap-on (clamp-on) ferrites** of mix 43 threaded in line on the coax just behind the feedpoint. 5–6 units provide enough impedance.

Reference for snap-on ferrites valid for VHF/UHF: Fair-Rite 0443164251 (cable ≤6.6 mm), Fair-Rite 0443167251 (cable ≤9.85 mm), or Fair-Rite 0443164151 (cable ≤12.7 mm), all in mix 43 material. Available from Mouser, DigiKey, or similar distributors.

The snap-ons open and close with your fingers, require no tools, and are completely reusable.

**Note:** Many commercial quad-type antennas have no choke and work perfectly. The quad has an intrinsically well-balanced geometry at the feedpoint. The choke is mainly for obtaining reliable measurements during tuning, not a requirement for normal use.

<p align="center">
  Close-up of the driven element solder joint
  Driven element with coax and sealing
</p>

### 4.3. Tuning procedure

#### Step 1 — Build and calibrate the Vf

Every real wire has Vf < 1. Bare copper in air sits around 0.97–0.99; insulated wires drop to 0.90–0.97 depending on the dielectric. The recommended procedure is to start from an approximate value and calibrate by measurement:

1. Calculate the dimensions of all elements with the [🧮 online calculator](https://openquad-calc.ea4ipw.es), using the typical starting Vf for your wire (0.99 bare copper, ≈0.91 thin PVC, ≈0.95 polyethylene, ≈0.97 Teflon; full table in [TEORIA.en.md § 2.2](TEORIA.en.md)). The underlying formula is `perimeter = k × λ × Vf`, with `λ = 299,792.458 / f(MHz)` mm and `k_driven ≈ 1.022` (see [TEORIA.en.md § 1](TEORIA.en.md)).
2. Build the full antenna with those dimensions.
3. Measure the resonance frequency of the assembled antenna with the VNA.
4. Enter the measured frequency into the [🧮 calculator](https://openquad-calc.ea4ipw.es) to obtain the real Vf and the corrected dimensions.
5. Shorten each loop to the new measurement — the wire clamps ([stls/regular_wire_clamp.stl](../stls/regular_wire_clamp.stl)) allow this adjustment without redoing the solder joint.

> See [TEORIA.en.md § 2.4](TEORIA.en.md) for more details.

**Do not try to tune the driven in isolation to the target frequency and then add the reflector expecting it to stay put.** Coupling always shifts the frequency; that's why we measure with the full antenna already assembled.

#### Step 2 — Add the directors, one by one

1. Mount Director 1 at 0.15λ in front of the driven. Its perimeter should be ~3% shorter than the driven.
2. Measure. The frequency may rise or fall slightly depending on the coupling.
3. If the SWR is acceptable, proceed to the next director.
4. Repeat for each additional director. Each one should be 3% shorter than the previous.

**Common problem: SWR rises sharply when adding a director.** The most frequent cause is that the director is too long (too close to the resonance frequency of the driven). When a parasitic resonates at the same frequency as the driven, it absorbs maximum energy and the SWR shoots up. **Solution:** verify that the director really is 3% shorter than the driven and trim it if necessary.

#### Step 3 — Final tuning

After mounting all the elements, a fine touch-up of the driven element may be needed to center the frequency. The directors rarely need a touch-up if they were cut correctly.

**Tip:** On the VNA, use the SWR vs. frequency view (not just the Smith chart) to clearly see where the minimum and the bandwidth are.

<p align="center">
  Wire clamp — Allen screw side
  Wire clamp — nut side
</p>

---

## 5. Common problems and solutions

### The resonance frequency is much lower than expected

**Probable cause:** the Vf of the insulated wire has not been taken into account. A PVC wire can have Vf = 0.91–0.95, which electrically lengthens the elements.

**Solution:** measure the Vf empirically (step 1 of the procedure) and recalculate the dimensions.

### The SWR rises a lot when adding a director

**Probable cause:** the director is cut to the same length as the driven, or very close to it. When a parasitic resonates at the same frequency as the driven, it absorbs maximum energy.

**Solution:** verify that the director is 3% shorter than the driven. Trim it if necessary.

### The frequency drops when adding the reflector

**Cause:** inductive mutual coupling between reflector and driven. This is normal behavior, not an error.

**Solution:** precompensate the driven (tune it alone to a frequency higher than the target) or tune with driven + reflector mounted together.

### The frequency shifts when handling the antenna

**Cause:** at VHF/UHF, 1–2 mm of displacement at a corner easily changes the frequency.

**Solution:** secure the wires well on the spreaders before the definitive measurements, adjusting the tension so that the wire stays taut.

### The VNA measurements change when touching the cable

**Cause:** common-mode current on the outer braid of the coax. The VNA cable behaves as part of the antenna.

**Solution:** add snap-on ferrites (mix 43) at the feedpoint. If you do not have ferrites, at least keep the same cable layout between measurements.

### The SWR is good but the F/B is poor

**Probable cause:** the reflector is not well tuned. SWR and F/B are optimized at different reflector lengths.

**Solution:** try lengthening or shortening the reflector by 1–2%. Alternatively, use a shorted stub on the reflector to tune it without changing its physical length.

---

## 6. Result of the reference build

The antenna documented as an example in this guide (5 elements, 435 MHz, 0.5 mm² PVC wire, measured Vf of 0.91) achieved the following measured results:

- **SWR:** 1.1 at the minimum point (432 MHz), <1.6 at 435 MHz
- **Measured F/B:** ~6 S units of difference (S9 forward, S3 rearward) ≈ 30–36 dB
- **Impedance at resonance:** close to 50 Ω
- **Useful bandwidth (SWR < 2):** ~430–440 MHz

> To compare with the theoretical values expected in other configurations (2–7 elements) and the equivalence with Yagi, see [TEORIA.en.md § 4](TEORIA.en.md).

<p align="center">
  3/4 view of the completed 5-element 435 MHz antenna
</p>

---

## 7. Pre-built parts

CI publishes a pre-rendered set of STLs for the most common boom and spreader sizes on every release. Each combination ships as a single zip containing the three printable parts (`all_in_one`, `driven_element`, `regular_wire_clamp`) plus PNG previews. Download the combination that matches your hardware and start printing — no OpenSCAD needed.

If none of the pre-rendered combinations matches your hardware, see [§ 7.4](#74-build-a-custom-size) below to render your own.

### 7.1. All-in-one block (boom collar + 4 clamps)

<p align="center">
  All-in-one block with clamps open
  All-in-one block with clamps closed against the boom collar
</p>

Boom shape × boom dimension as rows, spreader diameter as columns.

| Boom \ Spreader | 4.05 mm | 6.07 mm | 8.10 mm |
|---|---|---|---|
| **Round 14.9 mm** |  |  |  |
| **Round 15.9 mm** |  |  |  |
| **Round 19.9 mm** |  |  |  |
| **Square 14.9 mm** |  |  |  |
| **Square 15.9 mm** |  |  |  |
| **Square 19.9 mm** |  |  |  |

### 7.2. Spreader clamps

These two parts depend only on the spreader diameter (the boom shape and dimension don't matter), so there are only three variants of each.

| Spreader | Driven element | Wire clamp (parasitic) |
|---|---|---|
| **4.05 mm** |  |  |
| **6.07 mm** |  |  |
| **8.10 mm** |  |  |

### 7.3. Downloads

Each link is a zip with the three STLs plus PNG previews for that combination. Always pulls from the **latest release**.

| Boom \ Spreader | 4.05 mm | 6.07 mm | 8.10 mm |
|---|---|---|---|
| **Round 14.9 mm** | [zip](https://github.com/mangelajo/openquad-antenna/releases/latest/download/round_boom_14.9mm_spreaders_4.05mm.zip) | [zip](https://github.com/mangelajo/openquad-antenna/releases/latest/download/round_boom_14.9mm_spreaders_6.07mm.zip) | [zip](https://github.com/mangelajo/openquad-antenna/releases/latest/download/round_boom_14.9mm_spreaders_8.10mm.zip) |
| **Round 15.9 mm** | [zip](https://github.com/mangelajo/openquad-antenna/releases/latest/download/round_boom_15.9mm_spreaders_4.05mm.zip) | [zip](https://github.com/mangelajo/openquad-antenna/releases/latest/download/round_boom_15.9mm_spreaders_6.07mm.zip) | [zip](https://github.com/mangelajo/openquad-antenna/releases/latest/download/round_boom_15.9mm_spreaders_8.10mm.zip) |
| **Round 19.9 mm** | [zip](https://github.com/mangelajo/openquad-antenna/releases/latest/download/round_boom_19.9mm_spreaders_4.05mm.zip) | [zip](https://github.com/mangelajo/openquad-antenna/releases/latest/download/round_boom_19.9mm_spreaders_6.07mm.zip) | [zip](https://github.com/mangelajo/openquad-antenna/releases/latest/download/round_boom_19.9mm_spreaders_8.10mm.zip) |
| **Square 14.9 mm** | [zip](https://github.com/mangelajo/openquad-antenna/releases/latest/download/square_boom_14.9mm_spreaders_4.05mm.zip) | [zip](https://github.com/mangelajo/openquad-antenna/releases/latest/download/square_boom_14.9mm_spreaders_6.07mm.zip) | [zip](https://github.com/mangelajo/openquad-antenna/releases/latest/download/square_boom_14.9mm_spreaders_8.10mm.zip) |
| **Square 15.9 mm** | [zip](https://github.com/mangelajo/openquad-antenna/releases/latest/download/square_boom_15.9mm_spreaders_4.05mm.zip) | [zip](https://github.com/mangelajo/openquad-antenna/releases/latest/download/square_boom_15.9mm_spreaders_6.07mm.zip) | [zip](https://github.com/mangelajo/openquad-antenna/releases/latest/download/square_boom_15.9mm_spreaders_8.10mm.zip) |
| **Square 19.9 mm** | [zip](https://github.com/mangelajo/openquad-antenna/releases/latest/download/square_boom_19.9mm_spreaders_4.05mm.zip) | [zip](https://github.com/mangelajo/openquad-antenna/releases/latest/download/square_boom_19.9mm_spreaders_6.07mm.zip) | [zip](https://github.com/mangelajo/openquad-antenna/releases/latest/download/square_boom_19.9mm_spreaders_8.10mm.zip) |

### 7.4. Build a custom size

If none of the pre-rendered combinations matches your hardware (or you want to experiment with other diameters), you can render the parts yourself. There are three knobs that you'll normally touch, all on the [src/all_in_one.scad](../src/all_in_one.scad) file:

- `boom_is_round` — `true` for round tubing, `false` for square.
- `boom_dia` (round) **or** `boom_side` (square) — the boom's outer dimension in mm.
- `spreaders_dia` — outer diameter of your spreader rod in mm.

The driven element and regular wire clamp ([src/antenna_spreader_clamp.scad](../src/antenna_spreader_clamp.scad)) only depend on `spreaders_dia` and on `driven_element` (`true` / `false`).

> ⚠️ **Pre-check the all-in-one visually before slicing — especially the pivots.** This part is print-in-place: the four clamps are printed already attached to the central collar by thin pivot cylinders, with small lock-detent spheres that hold each clamp open (for printing) or folded (for transport). Unusual boom or spreader sizes can shift the geometry enough to fuse the pivots solid (clamp won't pivot) or open them up too much (lock detent won't catch). Always render the model with **F6** in OpenSCAD, then zoom into one of the pivots and confirm:
>
> - The pivot cylinder has a clear ring of clearance around it inside its hole — no fused walls.
> - The lock-detent spheres are visible as distinct features, not merged into the surrounding material.
> - The clamp body keeps a continuous gap to the pivot frame plates.
>
> If anything looks fused or zero-thickness, the values to nudge are `print_gap` and `pivot_clearance` (in the *Hidden* section near the top of [src/all_in_one.scad](../src/all_in_one.scad)).

**Option A — OpenSCAD GUI**

1. Install OpenSCAD (download a recent **2026.x nightly** from <https://openscad.org/downloads.html> — the older stable 2021.01 release is missing the manifold backend used here).
2. Open [src/all_in_one.scad](../src/all_in_one.scad). The Customizer panel on the right exposes only the four boom/spreader knobs above (the rest of the model's parameters are intentionally hidden).
3. Edit the values, press **F5** for a quick preview, then **F6** (the clock icon) to render the full geometry.
4. Inspect (especially the pivots — see warning above), then **File → Export → Export as STL…**.
5. Repeat with [src/antenna_spreader_clamp.scad](../src/antenna_spreader_clamp.scad) for `driven_element=true` and `driven_element=false`.

**Option B — CLI / Makefile**

The repo ships a [Makefile](../Makefile) that wraps the OpenSCAD CLI. Requires `openscad` on your `PATH` (or pass `OPENSCAD=/path/to/openscad`).

The simplest way: edit the `boom_…` / `spreaders_dia` defaults at the top of [src/all_in_one.scad](../src/all_in_one.scad), then:

```bash
make            # builds build/all_in_one.stl, build/driven_element.stl, build/regular_wire_clamp.stl
make renders    # also generates 800×800 PNG previews
```

Or call OpenSCAD directly with `-D` overrides, leaving the source files untouched:

```bash
openscad --backend=manifold -o my_block.stl \
  -D 'boom_is_round=true' -D 'boom_dia=22.0' -D 'spreaders_dia=5.0' \
  src/all_in_one.scad

openscad --backend=manifold -o driven.stl \
  -D 'driven_element=true' -D 'spreaders_dia=5.0' \
  src/antenna_spreader_clamp.scad

openscad --backend=manifold -o wire_clamp.stl \
  -D 'driven_element=false' -D 'spreaders_dia=5.0' \
  src/antenna_spreader_clamp.scad
```

Run `make help` to see all the available targets (`all`, `matrix`, `zip`, `renders`, `docs-images`, `clean`).

---

*73 from EA4IPW — OpenQuad v1.0*

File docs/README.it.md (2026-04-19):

# OpenQuad — Antenna Cubical Quad modulare e pieghevole

**Di EA4IPW — Caso pratico: costruzione di una quad di 5 elementi per 435 MHz**

<p align="center">
  Diagramma del progetto
</p>

---

## 1. Cos'è questo progetto

Questo progetto documenta un **design di antenna Cubical Quad modulare e pieghevole** pensato per essere realizzato con parti stampate in 3D, aste di fibra di vetro o legno come spreader e un boom in PVC, legno o alluminio.

Le caratteristiche principali del progetto sono:

- **Modulare:** ogni elemento (riflettore, driven, direttori) si monta su un *blocco* indipendente che scorre e si fissa al boom. Puoi costruire l'antenna con 2, 3, 5, 6, 7 .. elementi usando lo stesso hardware.
- **Pieghevole:** gli spreader ruotano sul blocco, in modo che l'antenna possa essere richiusa per il trasporto o lo stoccaggio e dispiegata in pochi secondi per operare.
- **Scalabile per banda:** il design parametrico in OpenSCAD ([src/all_in_one.scad](../src/all_in_one.scad)) permette di regolare il diametro del boom e degli spreader e rigenerare il pezzo per altre dimensioni di boom e spreader.

- **Regolabile:** i loop sono fissati con morsetti stampati ([stls/regular_wire_clamp.stl](../stls/regular_wire_clamp.stl)) che permettono di tagliare e fissare nuovamente il cavo durante il tuning.

Questa guida documenta il processo pratico di costruzione e regolazione passo passo. I fondamenti teorici (origine delle formule 1005/1030/975, effetto del velocity factor, prestazioni attese, riferimenti bibliografici) sono trattati in un documento separato:

> 📘 **[TEORIA.it.md](TEORIA.it.md) — Fondamenti teorici e riferimenti**

Le formule sono valide per qualsiasi frequenza; come esempio pratico dettagliato è documentata una costruzione reale per la banda dei 70 cm (435 MHz) con cavo da installazione PVC da 0.5 mm².

<p align="center">
  Antenna dispiegata (5 elementi, 435 MHz)
  Antenna richiusa per il trasporto
</p>

---

## 2. Dimensioni per la costruzione di riferimento (435 MHz, Vf = 0.91)

Le seguenti dimensioni corrispondono alla costruzione reale documentata in questa guida, utilizzando cavo PVC da 0.5 mm² con velocity factor misurato di 0.91.

> Se costruisci per un'altra frequenza o con un altro tipo di cavo, consulta le formule generali e la procedura per misurare il Vf in [TEORIA.it.md § 2–3](TEORIA.it.md), oppure usa il [🧮 calcolatore online](https://openquad-calc.ea4ipw.es) per ottenere direttamente le dimensioni.

**Elementi:**

| Elemento | Perimetro (mm) | Perimetro (in) | Lato (mm) | Lato (in) | Spreader (mm) | Spreader (in) |
|---|---|---|---|---|---|---|
| Riflettore | 656.8 | 25.86 | 164.2 | 6.46 | 116.1 | 4.57 |
| Driven | 640.8 | 25.23 | 160.2 | 6.31 | 113.3 | 4.46 |
| Direttore 1 | 621.7 | 24.47 | 155.4 | 6.12 | 109.9 | 4.33 |
| Direttore 2 | 603.0 | 23.74 | 150.8 | 5.93 | 106.6 | 4.20 |
| Direttore 3 | 584.9 | 23.03 | 146.2 | 5.76 | 103.4 | 4.07 |
| Direttore 4 | 567.4 | 22.34 | 141.8 | 5.58 | 100.3 | 3.95 |
| Direttore 5 | 550.4 | 21.67 | 137.6 | 5.42 | 97.3 | 3.83 |

**Spaziature:**

| Tratto | Distanza (mm) | Distanza (in) |
|---|---|---|
| Riflettore → Driven | 137.9 | 5.43 |
| Driven → Direttore 1 | 103.4 | 4.07 |
| Direttore → Direttore | 103.4 | 4.07 |

**Lunghezza totale del boom a seconda della configurazione:**

| Configurazione | Boom (mm) | Boom (in) |
|---|---|---|
| 2 elem (R + DE) | 137.9 | 5.43 |
| 3 elem (R + DE + D1) | 241.4 | 9.50 |
| 4 elem (R + DE + D1 + D2) | 344.8 | 13.57 |
| 5 elem (R + DE + D1–D3) | 448.3 | 17.65 |
| 6 elem (R + DE + D1–D4) | 551.7 | 21.72 |
| 7 elem (R + DE + D1–D5) | 655.2 | 25.80 |

---

## 3. Materiali

Riepilogo di ciò che serve per costruire l'antenna. Le sezioni seguenti dettagliano alternative, dimensionamento e motivazioni.

| Materiale | Specifica consigliata | Quantità | Sottosezione |
|---|---|---|---|
| Cavo di rame (elementi) | PVC 0.5 mm² (VHF/UHF); 1–2 mm Ø nudo o isolato (HF) | Secondo i perimetri (§2) | [3.1](#31-cavo-per-gli-elementi) |
| Boom | Tubo di alluminio, PVC o legno (quadrato o circolare) | 1, lunghezza a seconda della configurazione (§2) | [3.2](#32-boom) |
| Spreader | Asta non conduttrice (fibra di vetro, faggio o PVC), 4–8 mm Ø in VHF/UHF | 4 per elemento | [3.3](#33-spreader) |
| Viti a brugola M3 × 12 mm | Hex socket cap (M3×8/M3×10 per spreader più sottili) | 4 per elemento | [3.4](#34-viteria-e-ritenzione) |
| Dadi M3 | Esagonali standard | 4 per elemento | [3.4](#34-viteria-e-ritenzione) |
| Elastico | Uno qualsiasi che abbracci il blocco ripiegato | 1 per elemento | [3.4](#34-viteria-e-ritenzione) |
| Coassiale + connettore | Secondo il tuo apparato (tipicamente RG-58/RG-316 in UHF) | 1 | — |
| Termorestringente | Vari diametri per isolare saldature del feedpoint e giunzioni | Pochi cm | — |
| Ferriti snap-on mix 43 (opzionale, regolazione) | Fair-Rite 0443164251/0443167251 a seconda del Ø del coassiale | 5–6 | [4.2](#42-choke-balun-opzionale-ma-raccomandato-per-la-misura) |

### 3.1. Cavo per gli elementi

Qualsiasi cavo di rame con o senza isolamento va bene. Per cavo isolato (PVC, polietilene), ricorda di applicare la correzione del Vf (vedi [TEORIA.it.md § 2](TEORIA.it.md)).

In VHF/UHF, sezioni da 0.5 mm² a 1.5 mm² funzionano bene. Il cavo più fine è più maneggevole; quello più grosso mantiene meglio la forma, la mia raccomandazione è quello da 0.5mm². A 435 MHz lo skin depth è di soli 3 µm, quindi tutta la corrente scorre sulla superficie del conduttore. La differenza di perdite tra 0.5 mm² e 1.5 mm² è di ~0.025 dB — completamente trascurabile. La larghezza di banda si riduce di ~8% con il cavo più fine, il che non è nemmeno significativo nella pratica.

In HF, dove gli elementi sono molto più grandi, si usa tipicamente cavo di rame da 1–2 mm di diametro (nudo o isolato), o addirittura cavo multifilare per ridurre il peso.

Per potenze fino a 50W non c'è alcun problema con cavo sottile. Il limite pratico è dato dalle saldature e dall'isolamento (il PVC si ammorbidisce a ~70°C), non dal conduttore.

Quando unisci tratte di cavo o chiudi un loop, spela circa 10 mm da ciascuna estremità, uniscile in parallelo (intrecciando o con una giunzione Western Union), salda con stagno abbondante e proteggi la giunzione con guaina termorestringente.

<p align="center">
  10 mm di cavo spelato prima di saldare
  Giunzione delle due estremità prima della saldatura
</p>
<p align="center">
  Giunzione saldata
  Guaina termorestringente applicata sulla saldatura
</p>

### 3.2. Boom

L'alluminio è ideale: leggero, rigido e facile da lavorare. Un tubo quadrato o circolare di sezione adeguata alle dimensioni dell'antenna è sufficiente. Per UHF anche un tubo di PVC va perfettamente bene.

**Un boom metallico influisce sull'antenna?** In una quad, a differenza di una Yagi, il boom è perpendicolare al piano dei loop e gli elementi sono distanziati dal boom dagli spreader. L'effetto è minimo o inesistente. **Non è necessaria alcuna correzione del boom** come in una Yagi.

Un boom di legno funziona ugualmente ma è più pesante e assorbe umidità. Il suo effetto dielettrico (εr ≈ 2) potrebbe spostare la frequenza di ~0.1% — irrilevante nella pratica.

Se il boom è circolare invece che quadrato, non c'è differenza elettrica. L'unica considerazione è meccanica: assicurarsi che gli hub degli spreader rimangano fissati nella stessa orientazione angolare (vedi sezione 3.5).

<p align="center">
  Elemento montato su boom di PVC
</p>

### 3.3. Spreader

Aste di fibra di vetro, faggio, o PVC. Devono essere di materiale non conduttore. Il diametro appropriato dipende dalla banda: in VHF/UHF, aste da 4–8 mm sono sufficienti.

<p align="center">
  Hub stampati e aste spreader tagliate, pronte al montaggio
</p>

### 3.4. Viteria e ritenzione

Ogni elemento richiede una piccola quantità di viteria standard per chiudere le clamp sugli spreader e tenere il blocco print-in-place ripiegato durante il trasporto:

- **Viti a brugola (hex socket cap) M3 × 12 mm — 4 per elemento.** Una per ogni clamp di spreader; stringono le due metà della clamp attorno all'asta. La lunghezza di 12 mm è dimensionata per uno **spreader da 8 mm** — spreader più sottili (4–6 mm) usano un corpo clamp più fine e possono richiedere una vite più corta (M3×8 o M3×10); verifica la profondità del canale della vite sul pezzo renderizzato prima di acquistare. La sede del dado e la tolleranza della vite sono dimensionate per M3 in [src/antenna_spreader_clamp.scad](../src/antenna_spreader_clamp.scad).
- **Dadi M3 — 4 per elemento.** Si alloggiano nella tasca esagonale di ogni clamp prima di serrare la vite.
- **Elastico — 1 per elemento.** Avvolge il blocco `all_in_one` ripiegato per tenere le quattro clamp chiuse contro il collare del boom durante trasporto e stoccaggio.

<p align="center">
  Blocchi montati con viteria M3
</p>

### 3.5. Allineamento degli elementi

Tutti i loop quadrati devono essere **allineati nella stessa orientazione rotazionale** sul boom. Se un elemento viene ruotato rispetto agli altri, l'accoppiamento tra gli elementi degrada perché i segmenti di corrente cessano di essere paralleli.

- **Pochi gradi di errore:** effetto trascurabile.
- **45° di rotazione:** accoppiamento seriamente degradato, perdita di guadagno e F/B.

Con boom quadrato l'allineamento è naturale. Con boom circolare, assicura l'orientazione con un grano (vite senza testa), una spina passante, o una goccia di colla.

<p align="center">
  Elemento dispiegato (spreader aperti a X)
  Elemento richiuso (spreader chiusi)
</p>

---

## 4. Regolazione passo passo

### 4.1. Strumenti necessari

- Analizzatore di antenne (NanoVNA, LiteVNA, o simile)
- Cavo coassiale corto con connettore per il VNA
- Saldatore e stagno
- Righello millimetrato o calibro digitale
- Tronchesine di precisione

<p align="center">
  NanoVNA che mostra la carta di Smith e l'SWR dell'antenna
</p>

### 4.2. Choke balun (opzionale ma raccomandato per la misura)

Un choke balun al feedpoint migliora l'affidabilità delle misure impedendo che la calza del coassiale irradi e alteri i risultati. Senza choke, toccare o muovere il cavo del VNA può cambiare le letture.

**Per HF:** un choke avvolto classico funziona bene: 6–10 spire di coassiale su un toroide di ferrite (FT-140-43 o simile).

**Per VHF/UHF:** NON usare un choke avvolto — alle frequenze alte la capacità tra le spire crea risonanze parassite. Al suo posto, usa **ferriti snap-on (clamp-on)** di mix 43 infilate in linea sul coassiale appena dietro il feedpoint. 5–6 unità forniscono impedenza sufficiente.

Riferimento di ferriti snap-on adatte per VHF/UHF: Fair-Rite 0443164251 (cavo ≤6.6 mm), Fair-Rite 0443167251 (cavo ≤9.85 mm), o Fair-Rite 0443164151 (cavo ≤12.7 mm), tutte in materiale mix 43. Disponibili su Mouser, DigiKey, o distributori simili.

Le snap-on si aprono e chiudono con le dita, non richiedono attrezzi, e sono completamente riutilizzabili.

**Nota:** Molte antenne commerciali di tipo quad non hanno choke e funzionano perfettamente. La quad ha una geometria intrinsecamente ben bilanciata al feedpoint. Il choke serve principalmente per ottenere misure affidabili durante la regolazione, non è un requisito per l'uso normale.

<p align="center">
  Dettaglio della saldatura del driven
  Driven element con coassiale e sigillatura
</p>

### 4.3. Procedura di regolazione

#### Passo 1 — Costruire e calibrare il Vf

Ogni cavo reale ha Vf < 1. Il rame nudo in aria si aggira tra 0.97 e 0.99; i cavi con isolamento scendono a 0.90–0.97 a seconda del dielettrico. La procedura consigliata è partire da un valore approssimato e calibrare misurando:

1. Calcola le dimensioni di tutti gli elementi con il [🧮 calcolatore online](https://openquad-calc.ea4ipw.es), usando come Vf di partenza il valore tipico del tuo cavo (0.99 rame nudo, ≈0.91 PVC sottile, ≈0.95 polietilene, ≈0.97 teflon; tabella completa in [TEORIA.it.md § 2.2](TEORIA.it.md)). La formula sottostante è `perimetro = k × λ × Vf`, con `λ = 299,792.458 / f(MHz)` mm e `k_driven ≈ 1.022` (vedi [TEORIA.it.md § 1](TEORIA.it.md)).
2. Monta l'antenna completa con quelle dimensioni.
3. Misura la frequenza di risonanza dell'insieme con il VNA.
4. Inserisci la frequenza misurata nel [🧮 calcolatore](https://openquad-calc.ea4ipw.es) per ottenere il Vf reale e le dimensioni corrette.
5. Accorcia ogni loop alla nuova misura — i morsetti per il filo ([stls/regular_wire_clamp.stl](../stls/regular_wire_clamp.stl)) permettono questa regolazione senza rifare la saldatura.

> Vedi [TEORIA.it.md § 2.4](TEORIA.it.md) per maggiori dettagli.

**Non tentare di regolare il driven isolato alla frequenza obiettivo e poi aggiungere il riflettore sperando che si mantenga.** L'accoppiamento sposta sempre la frequenza; per questo misuriamo con l'antenna completa già montata.

#### Passo 2 — Aggiungere i direttori, uno a uno

1. Monta il Direttore 1 a 0.15λ davanti al driven. Il suo perimetro deve essere ~3% più piccolo del driven.
2. Misura. La frequenza può salire o scendere leggermente a seconda dell'accoppiamento.
3. Se l'SWR è accettabile, procedi al direttore successivo.
4. Ripeti per ogni direttore aggiuntivo. Ognuno deve essere un 3% più corto del precedente.

**Problema comune: l'SWR sale bruscamente aggiungendo un direttore.** La causa più frequente è che il direttore è troppo lungo (troppo vicino alla frequenza di risonanza del driven). Quando un parassita risuona alla stessa frequenza del driven, assorbe la massima energia e l'SWR va alle stelle. **Soluzione:** verifica che il direttore sia realmente un 3% più corto del driven e accorcialo se necessario.

#### Passo 3 — Regolazione finale

Dopo aver montato tutti gli elementi, può essere necessario un ritocco fine del driven element per centrare la frequenza. I direttori raramente necessitano di ritocchi se sono stati tagliati correttamente.

**Tip:** Sul VNA, usa la vista di SWR vs frequenza (non solo la carta di Smith) per vedere chiaramente dov'è il minimo e la larghezza di banda.

<p align="center">
  Morsetto del filo — lato della vite a brugola
  Morsetto del filo — lato del dado
</p>

---

## 5. Problemi frequenti e soluzioni

### La frequenza di risonanza è molto al di sotto del previsto

**Causa probabile:** non è stato tenuto conto del Vf del cavo isolato. Un cavo PVC può avere Vf = 0.91–0.95, il che allunga elettricamente gli elementi.

**Soluzione:** misura il Vf empiricamente (passo 1 della procedura) e ricalcola le dimensioni.

### L'SWR sale molto aggiungendo un direttore

**Causa probabile:** il direttore è tagliato alla stessa lunghezza del driven, o molto vicina. Quando un parassita risuona alla stessa frequenza del driven, assorbe la massima energia.

**Soluzione:** verifica che il direttore sia un 3% più corto del driven. Accorcialo se necessario.

### La frequenza scende aggiungendo il riflettore

**Causa:** accoppiamento mutuo induttivo tra riflettore e driven. È comportamento normale, non un errore.

**Soluzione:** precompensa il driven (regolandolo da solo a una frequenza più alta di quella obiettivo) oppure regola con driven + riflettore montati insieme.

### La frequenza si sposta maneggiando l'antenna

**Causa:** in VHF/UHF, 1–2 mm di spostamento in un angolo cambiano facilmente la frequenza.

**Soluzione:** fissa bene i cavi sugli spreader prima delle misure definitive, regolando la tensione in modo che il cavo rimanga teso.

### Le misure del VNA cambiano toccando il cavo

**Causa:** corrente di modo comune sulla calza esterna del coassiale. Il cavo del VNA si comporta come parte dell'antenna.

**Soluzione:** aggiungi ferriti snap-on (mix 43) al feedpoint. Se non hai ferriti, almeno mantieni la stessa disposizione del cavo tra le misure.

### L'SWR è buono ma il F/B è scarso

**Causa probabile:** il riflettore non è ben regolato. L'SWR e il F/B si ottimizzano a lunghezze diverse del riflettore.

**Soluzione:** prova ad allungare o accorciare il riflettore dell'1–2%. In alternativa, usa uno stub cortocircuitato sul riflettore per regolarlo senza cambiarne la lunghezza fisica.

---

## 6. Risultato della costruzione di riferimento

L'antenna documentata come esempio in questa guida (5 elementi, 435 MHz, cavo PVC da 0.5 mm², Vf misurato di 0.91) ha raggiunto i seguenti risultati misurati:

- **SWR:** 1.1 nel punto di minimo (432 MHz), <1.6 a 435 MHz
- **F/B misurato:** ~6 unità S di differenza (S9 frontale, S3 posteriore) ≈ 30–36 dB
- **Impedenza in risonanza:** prossima a 50 Ω
- **Larghezza di banda utile (SWR < 2):** ~430–440 MHz

> Per confrontare con i valori teorici attesi in altre configurazioni (2–7 elementi) e l'equivalenza con Yagi, vedi [TEORIA.it.md § 4](TEORIA.it.md).

<p align="center">
  Vista 3/4 dell'antenna di riferimento a 5 elementi per 435 MHz
</p>

---

## 7. Parti pre-costruite

Il CI pubblica un set pre-renderizzato di STL per le dimensioni di boom e spreader più comuni a ogni release. Ogni combinazione è distribuita come un singolo zip contenente le tre parti stampabili (`all_in_one`, `driven_element`, `regular_wire_clamp`) più le anteprime PNG. Scarica la combinazione che corrisponde al tuo hardware e inizia a stampare — non serve OpenSCAD.

Se nessuna delle combinazioni pre-renderizzate corrisponde al tuo hardware, consulta il [§ 7.4](#74-costruire-una-dimensione-personalizzata) qui sotto per renderizzare la tua.

### 7.1. Blocco tutto-in-uno (collare del boom + 4 morsetti)

<p align="center">
  Blocco all-in-one con i morsetti aperti
  Blocco all-in-one con i morsetti chiusi contro il collare del boom
</p>

Forma del boom × dimensione del boom come righe, diametro dello spreader come colonne.

| Boom \ Spreader | 4.05 mm | 6.07 mm | 8.10 mm |
|---|---|---|---|
| **Tondo 14.9 mm** |  |  |  |
| **Tondo 15.9 mm** |  |  |  |
| **Tondo 19.9 mm** |  |  |  |
| **Quadrato 14.9 mm** |  |  |  |
| **Quadrato 15.9 mm** |  |  |  |
| **Quadrato 19.9 mm** |  |  |  |

### 7.2. Morsetti dello spreader

Queste due parti dipendono solo dal diametro dello spreader (la forma e la dimensione del boom non contano), quindi ci sono solo tre varianti di ciascuna.

| Spreader | Elemento eccitato | Morsetto del filo (parassita) |
|---|---|---|
| **4.05 mm** |  |  |
| **6.07 mm** |  |  |
| **8.10 mm** |  |  |

### 7.3. Download

Ogni link è un zip con i tre STL più le anteprime PNG per quella combinazione. Punta sempre all'**ultima release**.

| Boom \ Spreader | 4.05 mm | 6.07 mm | 8.10 mm |
|---|---|---|---|
| **Tondo 14.9 mm** | [zip](https://github.com/mangelajo/openquad-antenna/releases/latest/download/round_boom_14.9mm_spreaders_4.05mm.zip) | [zip](https://github.com/mangelajo/openquad-antenna/releases/latest/download/round_boom_14.9mm_spreaders_6.07mm.zip) | [zip](https://github.com/mangelajo/openquad-antenna/releases/latest/download/round_boom_14.9mm_spreaders_8.10mm.zip) |
| **Tondo 15.9 mm** | [zip](https://github.com/mangelajo/openquad-antenna/releases/latest/download/round_boom_15.9mm_spreaders_4.05mm.zip) | [zip](https://github.com/mangelajo/openquad-antenna/releases/latest/download/round_boom_15.9mm_spreaders_6.07mm.zip) | [zip](https://github.com/mangelajo/openquad-antenna/releases/latest/download/round_boom_15.9mm_spreaders_8.10mm.zip) |
| **Tondo 19.9 mm** | [zip](https://github.com/mangelajo/openquad-antenna/releases/latest/download/round_boom_19.9mm_spreaders_4.05mm.zip) | [zip](https://github.com/mangelajo/openquad-antenna/releases/latest/download/round_boom_19.9mm_spreaders_6.07mm.zip) | [zip](https://github.com/mangelajo/openquad-antenna/releases/latest/download/round_boom_19.9mm_spreaders_8.10mm.zip) |
| **Quadrato 14.9 mm** | [zip](https://github.com/mangelajo/openquad-antenna/releases/latest/download/square_boom_14.9mm_spreaders_4.05mm.zip) | [zip](https://github.com/mangelajo/openquad-antenna/releases/latest/download/square_boom_14.9mm_spreaders_6.07mm.zip) | [zip](https://github.com/mangelajo/openquad-antenna/releases/latest/download/square_boom_14.9mm_spreaders_8.10mm.zip) |
| **Quadrato 15.9 mm** | [zip](https://github.com/mangelajo/openquad-antenna/releases/latest/download/square_boom_15.9mm_spreaders_4.05mm.zip) | [zip](https://github.com/mangelajo/openquad-antenna/releases/latest/download/square_boom_15.9mm_spreaders_6.07mm.zip) | [zip](https://github.com/mangelajo/openquad-antenna/releases/latest/download/square_boom_15.9mm_spreaders_8.10mm.zip) |
| **Quadrato 19.9 mm** | [zip](https://github.com/mangelajo/openquad-antenna/releases/latest/download/square_boom_19.9mm_spreaders_4.05mm.zip) | [zip](https://github.com/mangelajo/openquad-antenna/releases/latest/download/square_boom_19.9mm_spreaders_6.07mm.zip) | [zip](https://github.com/mangelajo/openquad-antenna/releases/latest/download/square_boom_19.9mm_spreaders_8.10mm.zip) |

### 7.4. Costruire una dimensione personalizzata

Se nessuna delle combinazioni pre-renderizzate corrisponde al tuo hardware (o vuoi sperimentare con altri diametri), puoi renderizzare le parti da solo. Ci sono tre parametri che normalmente toccherai, tutti nel file [src/all_in_one.scad](../src/all_in_one.scad):

- `boom_is_round` — `true` per tubo tondo, `false` per quadrato.
- `boom_dia` (tondo) **o** `boom_side` (quadrato) — dimensione esterna del boom in mm.
- `spreaders_dia` — diametro esterno della tua bacchetta spreader in mm.

L'elemento eccitato e il morsetto del filo regolare ([src/antenna_spreader_clamp.scad](../src/antenna_spreader_clamp.scad)) dipendono solo da `spreaders_dia` e da `driven_element` (`true` / `false`).

> ⚠️ **Verifica visivamente il tutto-in-uno prima dello slicing — soprattutto i pivot.** Questa parte è print-in-place: i quattro morsetti vengono stampati già attaccati al collare centrale tramite cilindri di pivot sottili, con piccole sfere lock-detent che tengono ogni morsetto aperto (per la stampa) o piegato (per il trasporto). Dimensioni insolite di boom o spreader possono spostare la geometria abbastanza da fondere i pivot in solido (il morsetto non ruota) o aprirli troppo (il lock-detent non si aggancia). Renderizza sempre il modello con **F6** in OpenSCAD, poi zooma su uno dei pivot e conferma:
>
> - Il cilindro del pivot ha un anello chiaro di gioco intorno dentro al suo foro — nessuna parete fusa.
> - Le sfere del lock-detent sono visibili come elementi distinti, non fuse con il materiale circostante.
> - Il corpo del morsetto mantiene un gap continuo verso le piastre del telaio del pivot.
>
> Se qualcosa sembra fuso o a spessore zero, i valori da regolare sono `print_gap` e `pivot_clearance` (nella sezione *Hidden* vicino all'inizio di [src/all_in_one.scad](../src/all_in_one.scad)).

**Opzione A — GUI di OpenSCAD**

1. Installa OpenSCAD (scarica una versione **nightly 2026.x** recente da <https://openscad.org/downloads.html> — la versione stabile 2021.01 non include il backend manifold usato qui).
2. Apri [src/all_in_one.scad](../src/all_in_one.scad). Il pannello Customizer sulla destra mostra solo i quattro parametri di boom/spreader sopra elencati (il resto dei parametri del modello è intenzionalmente nascosto).
3. Modifica i valori, premi **F5** per un'anteprima veloce, poi **F6** (l'icona dell'orologio) per renderizzare la geometria completa.
4. Ispeziona (soprattutto i pivot — vedi avviso sopra), poi **File → Esporta → Esporta come STL…**.
5. Ripeti con [src/antenna_spreader_clamp.scad](../src/antenna_spreader_clamp.scad) per `driven_element=true` e `driven_element=false`.

**Opzione B — CLI / Makefile**

Il repository include un [Makefile](../Makefile) che racchiude la CLI di OpenSCAD. Richiede `openscad` nel tuo `PATH` (oppure passa `OPENSCAD=/percorso/a/openscad`).

Il modo più semplice: modifica i valori predefiniti di `boom_…` / `spreaders_dia` all'inizio di [src/all_in_one.scad](../src/all_in_one.scad), poi:

```bash
make            # costruisce build/all_in_one.stl, build/driven_element.stl, build/regular_wire_clamp.stl
make renders    # genera anche anteprime PNG 800×800
```

Oppure chiama OpenSCAD direttamente con override `-D`, lasciando i file sorgente intatti:

```bash
openscad --backend=manifold -o my_block.stl \
  -D 'boom_is_round=true' -D 'boom_dia=22.0' -D 'spreaders_dia=5.0' \
  src/all_in_one.scad

openscad --backend=manifold -o driven.stl \
  -D 'driven_element=true' -D 'spreaders_dia=5.0' \
  src/antenna_spreader_clamp.scad

openscad --backend=manifold -o wire_clamp.stl \
  -D 'driven_element=false' -D 'spreaders_dia=5.0' \
  src/antenna_spreader_clamp.scad
```

Esegui `make help` per vedere tutti i target disponibili (`all`, `matrix`, `zip`, `renders`, `docs-images`, `clean`).

---

*73 da EA4IPW — OpenQuad v1.0*

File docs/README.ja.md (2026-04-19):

# OpenQuad — モジュラー式・折り畳み式 Cubical Quad アンテナ

**著者：EA4IPW — ケーススタディ：435 MHz 用 5 エレメントクワッドの製作**

<p align="center">
  設計図
</p>

---

## 1. この設計の概要

本プロジェクトは、**モジュラー式・折り畳み式の Cubical Quad アンテナ**の設計を文書化したものです。3D プリント部品、スプレッダーとしてのグラスファイバーまたは木製ロッド、そして PVC・木材・アルミ製ブームで製作することを想定しています。

主な設計上の特徴は次のとおりです。

- **モジュラー式：** 各エレメント（リフレクター、ドリブン、ディレクター）は独立した*ブロック*に取り付けられ、ブームにスライドして固定します。同じハードウェアで 2、3、5、6、7 … エレメントのアンテナを製作できます。
- **折り畳み式：** スプレッダーはブロック上でピボット（回転）するので、アンテナを運搬・収納のために折り畳み、運用時は数秒で展開できます。
- **バンドに合わせてスケーラブル：** OpenSCAD によるパラメトリック設計（[src/all_in_one.scad](../src/all_in_one.scad)）により、ブームとスプレッダーの直径を調整し、別サイズのブームやスプレッダー用にパーツを再生成できます。

- **調整可能：** ループは 3D プリント製のクランプ（[stls/regular_wire_clamp.stl](../stls/regular_wire_clamp.stl)）で固定され、チューニング中にケーブルを切り詰めて再固定できます。

本ガイドでは、製作と調整の実践的な手順を段階的に文書化します。理論的な背景（1005/1030/975 の公式の由来、Velocity Factor の影響、期待される性能、参考文献）は別ドキュメントで扱います。

> 📘 **[TEORIA.ja.md](TEORIA.ja.md) — 理論的背景と参考文献**

公式はどの周波数でも有効ですが、実践的な詳細例として、PVC 絶縁 0.5 mm² ケーブルを用いた 70 cm バンド（435 MHz）向けの実機製作を文書化しています。

<p align="center">
  展開したアンテナ（5 エレメント、435 MHz）
  運搬のために折り畳んだアンテナ
</p>

---

## 2. リファレンス製作の寸法（435 MHz、Vf = 0.91）

以下の寸法は、本ガイドで文書化した実機製作に対応するもので、0.5 mm² の PVC ケーブル（実測 Velocity Factor 0.91）を使用しています。

> 別の周波数や別の種類のケーブルで製作する場合は、一般公式と Vf の測定手順を [TEORIA.ja.md § 2–3](TEORIA.ja.md) で参照するか、[🧮 オンライン計算機](https://openquad-calc.ea4ipw.es) を使って直接寸法を得ることもできます。

**エレメント：**

| エレメント | 周長 (mm) | 周長 (in) | 辺 (mm) | 辺 (in) | スプレッダー (mm) | スプレッダー (in) |
|---|---|---|---|---|---|---|
| リフレクター | 656.8 | 25.86 | 164.2 | 6.46 | 116.1 | 4.57 |
| ドリブン | 640.8 | 25.23 | 160.2 | 6.31 | 113.3 | 4.46 |
| ディレクター 1 | 621.7 | 24.47 | 155.4 | 6.12 | 109.9 | 4.33 |
| ディレクター 2 | 603.0 | 23.74 | 150.8 | 5.93 | 106.6 | 4.20 |
| ディレクター 3 | 584.9 | 23.03 | 146.2 | 5.76 | 103.4 | 4.07 |
| ディレクター 4 | 567.4 | 22.34 | 141.8 | 5.58 | 100.3 | 3.95 |
| ディレクター 5 | 550.4 | 21.67 | 137.6 | 5.42 | 97.3 | 3.83 |

**間隔：**

| 区間 | 距離 (mm) | 距離 (in) |
|---|---|---|
| リフレクター → ドリブン | 137.9 | 5.43 |
| ドリブン → ディレクター 1 | 103.4 | 4.07 |
| ディレクター → ディレクター | 103.4 | 4.07 |

**構成ごとのブーム全長：**

| 構成 | ブーム (mm) | ブーム (in) |
|---|---|---|
| 2 エレメント (R + DE) | 137.9 | 5.43 |
| 3 エレメント (R + DE + D1) | 241.4 | 9.50 |
| 4 エレメント (R + DE + D1 + D2) | 344.8 | 13.57 |
| 5 エレメント (R + DE + D1–D3) | 448.3 | 17.65 |
| 6 エレメント (R + DE + D1–D4) | 551.7 | 21.72 |
| 7 エレメント (R + DE + D1–D5) | 655.2 | 25.80 |

---

## 3. 材料

アンテナを製作するのに必要なものの概要です。以降の節では代替案、寸法決定、根拠を詳しく説明します。

| 材料 | 推奨仕様 | 数量 | サブセクション |
|---|---|---|---|
| 銅導線（エレメント） | PVC 0.5 mm²（VHF/UHF）；1〜2 mm Ø 裸線または絶縁（HF） | 周長に応じて（§2） | [3.1](#31-エレメント用ケーブル) |
| ブーム | アルミ・PVC・木製のチューブ（角または丸） | 1 本、構成により長さが変わる（§2） | [3.2](#32-ブーム) |
| スプレッダー | 非導電性ロッド（グラスファイバー・ブナ材・PVC）、VHF/UHF では 4〜8 mm Ø | エレメントあたり 4 本 | [3.3](#33-スプレッダー) |
| M3 × 12 mm 六角穴付きボルト | Hex socket cap（細いスプレッダー用に M3×8/M3×10） | エレメントあたり 4 本 | [3.4](#34-締結部品と保持) |
| M3 ナット | 標準六角 | エレメントあたり 4 個 | [3.4](#34-締結部品と保持) |
| ゴムバンド | 折りたたんだブロックを巻けるもの | エレメントあたり 1 本 | [3.4](#34-締結部品と保持) |
| 同軸ケーブル + コネクター | 使用機器に合わせる（UHF では一般に RG-58/RG-316） | 1 | — |
| 熱収縮チューブ | 給電点のはんだ付けや接続部の絶縁用、各種径 | 数 cm | — |
| スナップオンフェライト mix 43（任意、調整用） | 同軸径に応じて Fair-Rite 0443164251/0443167251 | 5〜6 | [4.2](#42-チョークバラン測定時には任意だが推奨) |

### 3.1. エレメント用ケーブル

絶縁の有無にかかわらず、銅導線であれば何でも使えます。絶縁ケーブル（PVC、ポリエチレン）を使う場合は Vf 補正を忘れずに適用してください（[TEORIA.ja.md § 2](TEORIA.ja.md) を参照）。

VHF/UHF では 0.5 mm² から 1.5 mm² の断面積が適しています。細い方が取り回しやすく、太い方が形状を保ちやすいですが、推奨は 0.5 mm² です。435 MHz における表皮深さはわずか 3 µm で、すべての電流は導体表面を流れます。0.5 mm² と 1.5 mm² の損失差は約 0.025 dB で、完全に無視できます。細いケーブルでは帯域幅が約 8% 減少しますが、実用上は意味のある差ではありません。

HF ではエレメントがはるかに大きくなるため、典型的には直径 1〜2 mm の銅導線（裸銅線または絶縁付き）や、軽量化のために撚り線が使われます。

50 W までの電力であれば、細いケーブルでも全く問題ありません。実用上の限界は導体ではなく、はんだ付け部と絶縁（PVC は約 70°C で軟化します）にあります。

複数の電線を接続したりループを閉じたりする場合は、両端から約 10 mm の被覆を剥き、平行に重ねて（撚り合わせるか、ウェスタンユニオン接続で）、たっぷりのはんだで溶接し、熱収縮チューブで保護してください。

<p align="center">
  はんだ付け前の被覆を剥いだ 10 mm の導線
  はんだ付け前に両端を合わせた状態
</p>
<p align="center">
  はんだ付け済みの接続部
  接続部に被せた熱収縮チューブ
</p>

### 3.2. ブーム

アルミニウムが理想的です。軽く、剛性があり、加工も容易です。アンテナのサイズに適した断面の角パイプまたは丸パイプで十分です。UHF であれば PVC パイプでも問題なく使えます。

**金属製ブームはアンテナに影響するか？** クワッドでは、Yagi とは異なり、ブームはループの面に対して垂直であり、エレメントはスプレッダーによってブームから離されています。影響はごくわずか、あるいは皆無です。Yagi のように**ブーム補正は不要**です。

木製ブームも同様に機能しますが、重く吸湿します。その誘電効果（εr ≈ 2）は周波数を約 0.1% ずらす可能性がありますが、実用上は問題になりません。

ブームが角ではなく丸である場合、電気的な差はありません。唯一の考慮点は機械的なもので、スプレッダーのハブが同じ回転方向で固定されるようにすることです（セクション 3.5 参照）。

<p align="center">
  PVC ブームに取り付けたエレメント
</p>

### 3.3. スプレッダー

グラスファイバー、ブナ材、または PVC のロッドを使用します。非導電性の素材である必要があります。適切な直径はバンドによって異なり、VHF/UHF では 4〜8 mm のロッドで十分です。

<p align="center">
  3D プリントしたハブと、長さに切ったスプレッダーロッド
</p>

### 3.4. 締結部品と保持

各エレメントには、スプレッダーにクランプを閉じるため、および print-in-place ブロックを折りたたんだ状態で輸送するために、少量の標準締結部品が必要です：

- **M3 × 12 mm 六角穴付きボルト — 1 エレメントあたり 4 本。** スプレッダークランプ 1 個につき 1 本で、クランプの 2 つの半分をスプレッダーロッドの周りで締め付けます。12 mm の長さは **8 mm スプレッダー**用の寸法です。より細いスプレッダー（4〜6 mm）ではクランプ本体が薄くなるため、より短いボルト（M3×8 または M3×10）が必要になる場合があります。購入前にレンダリング済みの部品でボルト通路の深さを確認してください。ナット座とボルトのクリアランスは [src/antenna_spreader_clamp.scad](../src/antenna_spreader_clamp.scad) で M3 用に寸法設計されています。
- **M3 ナット — 1 エレメントあたり 4 個。** ボルトを締め付ける前に、各クランプの六角ポケットにはめ込みます。
- **ゴムバンド — 1 エレメントあたり 1 本。** 折りたたんだ `all_in_one` ブロックに巻きつけ、輸送および保管中に 4 つのクランプをブームカラーに閉じた状態で保持します。

<p align="center">
  M3 ハードウェアで組み立てたブロック
</p>

### 3.5. エレメントの整列

すべての正方形ループは、ブーム上で**同じ回転方向に整列**させる必要があります。あるエレメントが他に対して回転していると、電流セグメントが平行でなくなるため、エレメント間の結合が劣化します。

- **数度程度の誤差：** 影響は無視できます。
- **45° の回転：** 結合が著しく劣化し、利得と F/B 比が低下します。

角ブームでは整列は自然に得られます。丸ブームの場合は、止めねじ、貫通ピン、または少量の接着剤で向きを確保してください。

<p align="center">
  展開したエレメント（スプレッダーが X 形に開いた状態）
  折りたたんだエレメント（スプレッダーを閉じた状態）
</p>

---

## 4. 段階的な調整手順

### 4.1. 必要な工具

- アンテナアナライザ（NanoVNA、LiteVNA またはそれに準ずるもの）
- VNA 用コネクタ付きの短い同軸ケーブル
- はんだごてとはんだ
- ミリメートル目盛りの定規またはデジタルノギス
- 細刃のニッパー

<p align="center">
  アンテナのスミスチャートと SWR を表示している NanoVNA
</p>

### 4.2. チョークバラン（測定時には任意だが推奨）

給電点にチョークバランを入れると、同軸のシールド編組が放射して測定結果を乱すのを防ぎ、測定の信頼性が向上します。チョークがないと、VNA のケーブルに触れたり動かしたりするだけで読み値が変わることがあります。

**HF 用：** クラシックな巻線型チョークがよく機能します。フェライトトロイド（FT-140-43 など）に同軸を 6〜10 回巻きます。

**VHF/UHF 用：** 巻線型チョークは使用しないでください。高周波では巻線間の容量により寄生共振が発生します。その代わりに、給電点のすぐ後ろで同軸上に**スナップオン（クランプオン）フェライト**（mix 43）を連ねて通します。5〜6 個で十分なインピーダンスが得られます。

VHF/UHF に有効なスナップオンフェライトの例：Fair-Rite 0443164251（ケーブル径 ≤6.6 mm）、Fair-Rite 0443167251（ケーブル径 ≤9.85 mm）、または Fair-Rite 0443164151（ケーブル径 ≤12.7 mm）。いずれも mix 43 素材です。Mouser、DigiKey などの販売代理店で入手できます。

スナップオンは指で開閉でき、工具は不要で、完全に再利用可能です。

**注意：** 多くの市販のクワッド型アンテナはチョークを持たず、それで問題なく動作しています。クワッドは給電点で本質的にバランスの取れたジオメトリを持ちます。チョークは主に調整中の信頼できる測定のためのものであり、通常の運用における必須条件ではありません。

<p align="center">
  ドリブンエレメントのはんだ付け部の拡大
  同軸ケーブルを接続し防水処理したドリブンエレメント
</p>

### 4.3. 調整手順

#### ステップ 1 — 組み立てて Vf を較正する

実際の電線には必ず Vf < 1 があります。空気中の裸銅線は 0.97〜0.99 程度、絶縁付きケーブルは誘電体により 0.90〜0.97 まで下がります。推奨手順は、おおよその値から始めて測定により較正することです：

1. [🧮 オンライン計算機](https://openquad-calc.ea4ipw.es) を使い、あなたのケーブルの典型的な Vf を出発値として、すべてのエレメントの寸法を計算します（裸銅線 0.99、薄い PVC ≈0.91、ポリエチレン ≈0.95、テフロン ≈0.97。詳細な表は [TEORIA.ja.md § 2.2](TEORIA.ja.md)）。基礎となる式は `周長 = k × λ × Vf`、ここで `λ = 299,792.458 / f(MHz)` mm、`k_driven ≈ 1.022` です（[TEORIA.ja.md § 1](TEORIA.ja.md) 参照）。
2. その寸法でアンテナ全体を組み立てます。
3. VNA で組み立てたアンテナの共振周波数を測定します。
4. 測定した周波数を [🧮 計算機](https://openquad-calc.ea4ipw.es) に入力し、実際の Vf と補正後の寸法を得ます。
5. 各ループを新しい寸法に合わせて短くします — ワイヤークランプ（[stls/regular_wire_clamp.stl](../stls/regular_wire_clamp.stl)）により、はんだ付けをやり直さずに調整できます。

> 詳細は [TEORIA.ja.md § 2.4](TEORIA.ja.md) を参照してください。

**ドリブン単体で目標周波数に合わせ、その後リフレクターを追加して周波数が維持されると期待してはいけません。** 結合は常に周波数をずらします。だからこそ、アンテナ全体を組み立てた状態で測定します。

#### ステップ 2 — ディレクターを 1 つずつ追加する

1. ドリブンの前方 0.15λ の位置にディレクター 1 を取り付けます。その周長はドリブンより約 3% 短くします。
2. 測定します。結合の状態により周波数はわずかに上下します。
3. SWR が許容範囲なら、次のディレクターに進みます。
4. 追加の各ディレクターについて繰り返します。各ディレクターは前のものより 3% 短くします。

**よくある問題：ディレクターを追加した途端に SWR が急上昇する。** 最も多い原因は、ディレクターが長すぎる（ドリブンの共振周波数に近すぎる）ことです。寄生素子がドリブンと同じ周波数で共振すると最大のエネルギーを吸収し、SWR が跳ね上がります。**対策：** ディレクターが実際にドリブンより 3% 短いことを確認し、必要に応じて切り詰めます。

#### ステップ 3 — 最終調整

すべてのエレメントを取り付けたあと、周波数を中心に合わせるためにドリブンエレメントの微調整が必要になることがあります。ディレクターは正しくカットされていれば、ほとんど手直しを必要としません。

**ヒント：** VNA では、スミスチャートだけでなく「SWR vs 周波数」表示を使うと、最小点と帯域幅の位置が明確にわかります。

<p align="center">
  ワイヤークランプ — 六角穴付きボルト側
  ワイヤークランプ — ナット側
</p>

---

## 5. よくある問題と対処法

### 共振周波数が予想よりかなり低い

**考えられる原因：** 絶縁ケーブルの Vf を考慮していない。PVC ケーブルは Vf = 0.91〜0.95 となることがあり、エレメントを電気的に長くします。

**対策：** 手順のステップ 1 に従って Vf を実測し、寸法を再計算します。

### ディレクターを追加すると SWR が大幅に上がる

**考えられる原因：** ディレクターがドリブンと同じ長さ、あるいはごく近い長さにカットされている。寄生素子がドリブンと同じ周波数で共振すると最大のエネルギーを吸収します。

**対策：** ディレクターがドリブンより 3% 短いことを確認し、必要なら切り詰めます。

### リフレクターを追加すると周波数が下がる

**原因：** リフレクターとドリブンの間の誘導性の相互結合です。これは正常な動作であり、誤りではありません。

**対策：** ドリブンをプリコンペンセート（目標より少し高い周波数に単独で調整）するか、ドリブンとリフレクターを組み合わせた状態で調整します。

### アンテナを触ると周波数がずれる

**原因：** VHF/UHF では、コーナーが 1〜2 mm ずれるだけでも周波数が容易に変化します。

**対策：** 最終測定の前にスプレッダー上のケーブルをしっかり固定し、ケーブルがピンと張った状態になるようテンションを調整してください。

### VNA ケーブルに触れると測定値が変わる

**原因：** 同軸外側シールドのコモンモード電流。VNA のケーブルがアンテナの一部として振る舞っています。

**対策：** 給電点にスナップオンフェライト（mix 43）を追加します。フェライトが手元にない場合は、少なくとも測定間でケーブルの取り回しを変えないようにします。

### SWR は良好だが F/B 比が悪い

**考えられる原因：** リフレクターの調整が不適切。SWR と F/B 比は、リフレクターの異なる長さで最適化されます。

**対策：** リフレクターを 1〜2% 伸ばすか縮めて試します。あるいは、リフレクターに短絡スタブを付けて、物理的な長さを変えずに調整することもできます。

---

## 6. リファレンス製作の結果

本ガイドで例として文書化したアンテナ（5 エレメント、435 MHz、0.5 mm² PVC ケーブル、実測 Vf = 0.91）は、以下の測定結果を得ました。

- **SWR：** 最小点（432 MHz）で 1.1、435 MHz で <1.6
- **実測 F/B 比：** S メーターで約 6 単位の差（前方 S9、後方 S3）≈ 30〜36 dB
- **共振時インピーダンス：** 50 Ω に近い値
- **実用帯域幅（SWR < 2）：** 約 430〜440 MHz

> 他の構成（2〜7 エレメント）での理論値や Yagi との等価性と比較するには、[TEORIA.ja.md § 4](TEORIA.ja.md) を参照してください。

<p align="center">
  完成した 435 MHz 用 5 エレメントアンテナの 3/4 ビュー
</p>

---

## 7. 事前ビルド済みパーツ

リリースごとに、CI が最も一般的なブームとスプレッダーサイズの STL を事前レンダリングして公開します。各組み合わせは、3 つの印刷可能パーツ（`all_in_one`, `driven_element`, `regular_wire_clamp`）と PNG プレビューを含む単一の zip として配布されます。お使いのハードウェアに合う組み合わせをダウンロードして、すぐに印刷を開始できます — OpenSCAD は不要です。

事前レンダリングされた組み合わせがどれもハードウェアに合わない場合は、下の [§ 7.4](#74-カスタム-サイズをビルドする) を参照して自分でレンダリングしてください。

### 7.1. オールインワン ブロック（ブーム カラー + 4 つのクランプ）

<p align="center">
  クランプを開いた状態のオールインワンブロック
  クランプをブームカラーに閉じたオールインワンブロック
</p>

行：ブーム形状 × ブーム寸法、列：スプレッダー径。

| ブーム \ スプレッダー | 4.05 mm | 6.07 mm | 8.10 mm |
|---|---|---|---|
| **丸 14.9 mm** |  |  |  |
| **丸 15.9 mm** |  |  |  |
| **丸 19.9 mm** |  |  |  |
| **角 14.9 mm** |  |  |  |
| **角 15.9 mm** |  |  |  |
| **角 19.9 mm** |  |  |  |

### 7.2. スプレッダー クランプ

この 2 つのパーツはスプレッダー径のみに依存します（ブームの形状や寸法は関係ありません）。各 3 種類のバリエーションのみです。

| スプレッダー | 励振エレメント | ワイヤクランプ（寄生） |
|---|---|---|
| **4.05 mm** |  |  |
| **6.07 mm** |  |  |
| **8.10 mm** |  |  |

### 7.3. ダウンロード

各リンクは、その組み合わせの 3 つの STL と PNG プレビューを含む zip です。常に **最新のリリース** を取得します。

| ブーム \ スプレッダー | 4.05 mm | 6.07 mm | 8.10 mm |
|---|---|---|---|
| **丸 14.9 mm** | [zip](https://github.com/mangelajo/openquad-antenna/releases/latest/download/round_boom_14.9mm_spreaders_4.05mm.zip) | [zip](https://github.com/mangelajo/openquad-antenna/releases/latest/download/round_boom_14.9mm_spreaders_6.07mm.zip) | [zip](https://github.com/mangelajo/openquad-antenna/releases/latest/download/round_boom_14.9mm_spreaders_8.10mm.zip) |
| **丸 15.9 mm** | [zip](https://github.com/mangelajo/openquad-antenna/releases/latest/download/round_boom_15.9mm_spreaders_4.05mm.zip) | [zip](https://github.com/mangelajo/openquad-antenna/releases/latest/download/round_boom_15.9mm_spreaders_6.07mm.zip) | [zip](https://github.com/mangelajo/openquad-antenna/releases/latest/download/round_boom_15.9mm_spreaders_8.10mm.zip) |
| **丸 19.9 mm** | [zip](https://github.com/mangelajo/openquad-antenna/releases/latest/download/round_boom_19.9mm_spreaders_4.05mm.zip) | [zip](https://github.com/mangelajo/openquad-antenna/releases/latest/download/round_boom_19.9mm_spreaders_6.07mm.zip) | [zip](https://github.com/mangelajo/openquad-antenna/releases/latest/download/round_boom_19.9mm_spreaders_8.10mm.zip) |
| **角 14.9 mm** | [zip](https://github.com/mangelajo/openquad-antenna/releases/latest/download/square_boom_14.9mm_spreaders_4.05mm.zip) | [zip](https://github.com/mangelajo/openquad-antenna/releases/latest/download/square_boom_14.9mm_spreaders_6.07mm.zip) | [zip](https://github.com/mangelajo/openquad-antenna/releases/latest/download/square_boom_14.9mm_spreaders_8.10mm.zip) |
| **角 15.9 mm** | [zip](https://github.com/mangelajo/openquad-antenna/releases/latest/download/square_boom_15.9mm_spreaders_4.05mm.zip) | [zip](https://github.com/mangelajo/openquad-antenna/releases/latest/download/square_boom_15.9mm_spreaders_6.07mm.zip) | [zip](https://github.com/mangelajo/openquad-antenna/releases/latest/download/square_boom_15.9mm_spreaders_8.10mm.zip) |
| **角 19.9 mm** | [zip](https://github.com/mangelajo/openquad-antenna/releases/latest/download/square_boom_19.9mm_spreaders_4.05mm.zip) | [zip](https://github.com/mangelajo/openquad-antenna/releases/latest/download/square_boom_19.9mm_spreaders_6.07mm.zip) | [zip](https://github.com/mangelajo/openquad-antenna/releases/latest/download/square_boom_19.9mm_spreaders_8.10mm.zip) |

### 7.4. カスタム サイズをビルドする

事前レンダリング済みの組み合わせがどれもハードウェアに合わない（または他の直径を試したい）場合は、自分でパーツをレンダリングできます。通常変更する 3 つのパラメータはすべて [src/all_in_one.scad](../src/all_in_one.scad) ファイルにあります：

- `boom_is_round` — 丸パイプの場合 `true`、角パイプの場合 `false`。
- `boom_dia`（丸）**または** `boom_side`（角）— ブームの外寸（mm）。
- `spreaders_dia` — スプレッダー ロッドの外径（mm）。

励振エレメントと通常のワイヤクランプ（[src/antenna_spreader_clamp.scad](../src/antenna_spreader_clamp.scad)）は `spreaders_dia` と `driven_element`（`true` / `false`）のみに依存します。

> ⚠️ **スライスする前にオールインワンを視覚的にプリチェックしてください — 特にピボット部分。** このパーツはプリント・イン・プレース方式です：4 つのクランプは中央のカラーに細いピボット シリンダで取り付けられた状態で印刷され、小さなロック検出球が各クランプを開いた状態（印刷用）または折りたたんだ状態（運搬用）に保ちます。通常と異なるブームやスプレッダー サイズはジオメトリを変動させ、ピボットが融合してしまう（クランプが回転しない）またはクリアランスが大きすぎる（ロック検出が掛からない）ことがあります。OpenSCAD で **F6** を押してモデルをレンダリングし、ピボットの 1 つにズームインして以下を確認してください：
>
> - ピボット シリンダがその穴の中で明確なクリアランス リングを持っている — 融合した壁がない。
> - ロック検出球が独立した特徴として見える — 周囲の材料に融合していない。
> - クランプ本体がピボット フレーム プレートに対して連続したギャップを保っている。
>
> 何かが融合または厚さゼロに見える場合、調整する値は `print_gap` と `pivot_clearance` です（[src/all_in_one.scad](../src/all_in_one.scad) 上部の *Hidden* セクション内）。

**オプション A — OpenSCAD GUI**

1. OpenSCAD をインストールします（<https://openscad.org/downloads.html> から最新の **2026.x ナイトリー** をダウンロード — 古い安定版 2021.01 には、ここで使用される manifold バックエンドがありません）。
2. [src/all_in_one.scad](../src/all_in_one.scad) を開きます。右側のカスタマイザ パネルには、上記の 4 つのブーム/スプレッダー パラメータのみが表示されます（モデルの他のパラメータは意図的に非表示にしています）。
3. 値を編集し、**F5** で簡易プレビュー、続いて **F6**（時計アイコン）でフルジオメトリをレンダリングします。
4. 検査（特にピボット — 上記の警告を参照）し、**ファイル → エクスポート → STL としてエクスポート…**。
5. [src/antenna_spreader_clamp.scad](../src/antenna_spreader_clamp.scad) で `driven_element=true` と `driven_element=false` について繰り返します。

**オプション B — CLI / Makefile**

リポジトリには OpenSCAD CLI をラップした [Makefile](../Makefile) が含まれています。`openscad` が `PATH` に必要です（または `OPENSCAD=/path/to/openscad` を渡してください）。

最も簡単な方法：[src/all_in_one.scad](../src/all_in_one.scad) 上部の `boom_…` / `spreaders_dia` のデフォルト値を編集し、次のように実行します：

```bash
make            # build/all_in_one.stl, build/driven_element.stl, build/regular_wire_clamp.stl をビルド
make renders    # 800×800 PNG プレビューも生成
```

または、ソース ファイルを変更せずに `-D` オーバーライドで OpenSCAD を直接呼び出します：

```bash
openscad --backend=manifold -o my_block.stl \
  -D 'boom_is_round=true' -D 'boom_dia=22.0' -D 'spreaders_dia=5.0' \
  src/all_in_one.scad

openscad --backend=manifold -o driven.stl \
  -D 'driven_element=true' -D 'spreaders_dia=5.0' \
  src/antenna_spreader_clamp.scad

openscad --backend=manifold -o wire_clamp.stl \
  -D 'driven_element=false' -D 'spreaders_dia=5.0' \
  src/antenna_spreader_clamp.scad
```

`make help` を実行して、利用可能なすべてのターゲット（`all`, `matrix`, `zip`, `renders`, `docs-images`, `clean`）を表示します。

---

*73 from EA4IPW — OpenQuad v1.0*

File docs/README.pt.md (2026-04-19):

# OpenQuad — Antena Cubical Quad modular e dobrável

**Por EA4IPW — Caso prático: construção de um quad de 5 elementos para 435 MHz**

<p align="center">
  Diagrama do design
</p>

---

## 1. O que é este design

Este projeto documenta um **design de antena Cubical Quad modular e dobrável** pensado para ser fabricado com peças impressas em 3D, varetas de fibra de vidro ou madeira como spreaders e um boom de PVC, madeira ou alumínio.

As características principais do design são:

- **Modular:** cada elemento (refletor, driven, diretores) é montado sobre um *bloco* independente que desliza e se fixa ao boom. Podes construir a antena com 2, 3, 5, 6, 7 .. elementos usando o mesmo hardware.
- **Dobrável:** os spreaders pivotam sobre o bloco, de modo que a antena pode ser recolhida para transporte ou armazenamento e desdobrada em segundos para operar.
- **Escalável por banda:** o design paramétrico em OpenSCAD ([src/all_in_one.scad](../src/all_in_one.scad)) permite ajustar o diâmetro do boom e dos spreaders e regenerar a peça para outros tamanhos de boom e spreader.

- **Ajustável:** os loops são fixados com abraçadeiras impressas ([stls/regular_wire_clamp.stl](../stls/regular_wire_clamp.stl)) que permitem cortar e voltar a fixar o cabo durante o tuning.

Este guia documenta o processo prático de construção e ajuste passo a passo. Os fundamentos teóricos (origem das fórmulas 1005/1030/975, efeito do velocity factor, desempenho esperado, referências bibliográficas) são tratados num documento separado:

> 📘 **[TEORIA.pt.md](TEORIA.pt.md) — Fundamentos teóricos e referências**

As fórmulas são válidas para qualquer frequência; como exemplo prático detalhado documenta-se uma construção real para a banda de 70 cm (435 MHz) com cabo de instalação PVC de 0.5 mm².

<p align="center">
  Antena desdobrada (5 elementos, 435 MHz)
  Antena dobrada para transporte
</p>

---

## 2. Dimensões para a construção de referência (435 MHz, Vf = 0.91)

As seguintes dimensões correspondem à construção real documentada neste guia, usando cabo PVC de 0.5 mm² com velocity factor medido de 0.91.

> Se construíres para outra frequência ou com outro tipo de cabo, consulta as fórmulas gerais e o procedimento para medir o Vf em [TEORIA.pt.md § 2–3](TEORIA.pt.md), ou usa a [🧮 calculadora online](https://openquad-calc.ea4ipw.es) para obter as dimensões diretamente.

**Elementos:**

| Elemento | Perímetro (mm) | Perímetro (in) | Lado (mm) | Lado (in) | Spreader (mm) | Spreader (in) |
|---|---|---|---|---|---|---|
| Refletor | 656.8 | 25.86 | 164.2 | 6.46 | 116.1 | 4.57 |
| Driven | 640.8 | 25.23 | 160.2 | 6.31 | 113.3 | 4.46 |
| Diretor 1 | 621.7 | 24.47 | 155.4 | 6.12 | 109.9 | 4.33 |
| Diretor 2 | 603.0 | 23.74 | 150.8 | 5.93 | 106.6 | 4.20 |
| Diretor 3 | 584.9 | 23.03 | 146.2 | 5.76 | 103.4 | 4.07 |
| Diretor 4 | 567.4 | 22.34 | 141.8 | 5.58 | 100.3 | 3.95 |
| Diretor 5 | 550.4 | 21.67 | 137.6 | 5.42 | 97.3 | 3.83 |

**Espaçamentos:**

| Troço | Distância (mm) | Distância (in) |
|---|---|---|
| Refletor → Driven | 137.9 | 5.43 |
| Driven → Diretor 1 | 103.4 | 4.07 |
| Diretor → Diretor | 103.4 | 4.07 |

**Comprimento total do boom conforme configuração:**

| Configuração | Boom (mm) | Boom (in) |
|---|---|---|
| 2 elem (R + DE) | 137.9 | 5.43 |
| 3 elem (R + DE + D1) | 241.4 | 9.50 |
| 4 elem (R + DE + D1 + D2) | 344.8 | 13.57 |
| 5 elem (R + DE + D1–D3) | 448.3 | 17.65 |
| 6 elem (R + DE + D1–D4) | 551.7 | 21.72 |
| 7 elem (R + DE + D1–D5) | 655.2 | 25.80 |

---

## 3. Materiais

Resumo do que precisas para construir a antena. As secções seguintes detalham alternativas, dimensionamento e justificações.

| Material | Especificação recomendada | Quantidade | Subsecção |
|---|---|---|---|
| Cabo de cobre (elementos) | PVC 0.5 mm² (VHF/UHF); 1–2 mm Ø nu ou isolado (HF) | Segundo perímetros (§2) | [3.1](#31-cabo-para-os-elementos) |
| Boom | Tubo de alumínio, PVC ou madeira (quadrado ou circular) | 1, comprimento conforme configuração (§2) | [3.2](#32-boom) |
| Spreaders | Vareta não condutora (fibra de vidro, faia ou PVC), 4–8 mm Ø em VHF/UHF | 4 por elemento | [3.3](#33-spreaders) |
| Parafusos Allen M3 × 12 mm | Hex socket cap (M3×8/M3×10 para spreaders mais finos) | 4 por elemento | [3.4](#34-parafusaria-e-retenção) |
| Porcas M3 | Hexagonais padrão | 4 por elemento | [3.4](#34-parafusaria-e-retenção) |
| Elástico de borracha | Qualquer um que envolva o bloco dobrado | 1 por elemento | [3.4](#34-parafusaria-e-retenção) |
| Coaxial + conector | Conforme o teu equipamento (tipicamente RG-58/RG-316 em UHF) | 1 | — |
| Termorretrátil | Vários diâmetros para isolar soldaduras do feedpoint e emendas | Alguns cm | — |
| Ferrites snap-on mix 43 (opcional, ajuste) | Fair-Rite 0443164251/0443167251 conforme Ø do coaxial | 5–6 | [4.2](#42-choke-balun-opcional-mas-recomendado-para-a-medição) |

### 3.1. Cabo para os elementos

Qualquer cabo de cobre com ou sem isolamento serve. Para cabo isolado (PVC, polietileno), lembra-te de aplicar a correção de Vf (ver [TEORIA.pt.md § 2](TEORIA.pt.md)).

Em VHF/UHF, secções de 0.5 mm² a 1.5 mm² funcionam bem. O cabo mais fino é mais fácil de manusear; o mais grosso mantém melhor a forma, a minha recomendação é o de 0.5mm². A 435 MHz o skin depth é de apenas 3 µm, pelo que toda a corrente flui pela superfície do condutor. A diferença de perdas entre 0.5 mm² e 1.5 mm² é de ~0.025 dB — completamente desprezável. A largura de banda reduz-se ~8% com o cabo mais fino, o que também não é significativo na prática.

Em HF, onde os elementos são muito maiores, usa-se tipicamente cabo de cobre de 1–2 mm de diâmetro (nu ou isolado), ou mesmo cabo multifilar para reduzir peso.

Para potências até 50W não há qualquer problema com cabo fino. O limite prático é imposto pelas soldaduras e pelo isolamento (o PVC amolece a ~70°C), não pelo condutor.

Ao unir troços ou fechar um loop, descasca uns 10 mm de cada extremidade, junta-os em paralelo (torcendo ou com uma emenda Western Union), solda com estanho abundante e protege a união com manga termorretráctil.

<p align="center">
  10 mm de cabo descascado antes de soldar
  União das duas pontas antes da soldadura
</p>
<p align="center">
  Emenda soldada
  Manga termorretráctil aplicada sobre a soldadura
</p>

### 3.2. Boom

O alumínio é ideal: leve, rígido e fácil de trabalhar. Um tubo quadrado ou circular de secção apropriada ao tamanho da antena é suficiente. Para UHF um tubo de PVC também serve perfeitamente.

**Um boom metálico afeta a antena?** Num quad, ao contrário de um Yagi, o boom é perpendicular ao plano dos loops e os elementos estão separados do boom pelos spreaders. O efeito é mínimo ou inexistente. **Não é necessária correção de boom** como num Yagi.

Um boom de madeira funciona igualmente mas é mais pesado e absorve humidade. O seu efeito dielétrico (εr ≈ 2) poderia deslocar a frequência ~0.1% — irrelevante na prática.

Se o boom for circular em vez de quadrado, não há diferença elétrica. A única consideração é mecânica: garantir que os hubs dos spreaders fiquem fixados na mesma orientação angular (ver secção 3.5).

<p align="center">
  Elemento montado sobre boom de PVC
</p>

### 3.3. Spreaders

Varetas de fibra de vidro, faia, ou PVC. Devem ser de material não condutor. O diâmetro apropriado depende da banda: em VHF/UHF, varetas de 4–8 mm são suficientes

<p align="center">
  Hubs impressos e varetas de spreader cortadas à medida
</p>

### 3.4. Parafusaria e retenção

Cada elemento necessita de uma pequena quantidade de parafusaria padrão para fechar as abraçadeiras sobre os spreaders e manter o bloco print-in-place dobrado durante o transporte:

- **Parafusos Allen (hex socket cap) M3 × 12 mm — 4 por elemento.** Um por cada abraçadeira de spreader; apertam as duas metades da abraçadeira em torno da vareta. O comprimento de 12 mm está dimensionado para um **spreader de 8 mm** — spreaders mais finos (4–6 mm) usam um corpo de abraçadeira mais fino e podem precisar de um parafuso mais curto (M3×8 ou M3×10); verifica a profundidade do canal do parafuso na peça renderizada antes de comprar. O alojamento da porca e a folga do parafuso estão dimensionados para M3 em [src/antenna_spreader_clamp.scad](../src/antenna_spreader_clamp.scad).
- **Porcas M3 — 4 por elemento.** Assentam no bolso hexagonal de cada abraçadeira antes de apertar o parafuso.
- **Elástico de borracha — 1 por elemento.** Envolve o bloco `all_in_one` dobrado para manter as quatro abraçadeiras fechadas contra o colar do boom durante transporte e armazenamento.

<p align="center">
  Blocos montados com parafusaria M3
</p>

### 3.5. Alinhamento dos elementos

Todos os loops quadrados devem estar **alinhados na mesma orientação rotacional** sobre o boom. Se um elemento for rodado em relação aos demais, o acoplamento entre elementos degrada-se porque os segmentos de corrente deixam de ser paralelos.

- **Alguns graus de erro:** efeito desprezável.
- **45° de rotação:** acoplamento seriamente degradado, perda de ganho e F/B.

Com boom quadrado o alinhamento é natural. Com boom circular, garante a orientação com um parafuso sem cabeça, um pino passante, ou uma gota de cola.

<p align="center">
  Elemento desdobrado (spreaders abertos em X)
  Elemento dobrado (spreaders fechados)
</p>

---

## 4. Ajuste passo a passo

### 4.1. Ferramentas necessárias

- Analisador de antenas (NanoVNA, LiteVNA, ou similar)
- Cabo coaxial curto com conector para o VNA
- Ferro de soldar e estanho
- Régua milimetrada ou paquímetro digital
- Alicates de corte fino

<p align="center">
  NanoVNA a mostrar a carta de Smith e o SWR da antena
</p>

### 4.2. Choke balun (opcional mas recomendado para a medição)

Um choke balun no feedpoint melhora a fiabilidade das medições ao impedir que a malha do coaxial irradie e altere os resultados. Sem choke, tocar ou mover o cabo do VNA pode alterar as leituras.

**Para HF:** um choke bobinado clássico funciona bem: 6–10 voltas de coaxial sobre um toroide de ferrite (FT-140-43 ou similar).

**Para VHF/UHF:** NÃO uses um choke bobinado — em frequências altas a capacitância entre espiras cria ressonâncias parasitas. Em vez disso, usa **ferrites snap-on (clamp-on)** de mix 43 enfiadas em linha sobre o coaxial mesmo atrás do feedpoint. 5–6 unidades fornecem impedância suficiente.

Referência de ferrites snap-on válidas para VHF/UHF: Fair-Rite 0443164251 (cabo ≤6.6 mm), Fair-Rite 0443167251 (cabo ≤9.85 mm), ou Fair-Rite 0443164151 (cabo ≤12.7 mm), todas em material mix 43. Disponíveis na Mouser, DigiKey, ou distribuidores similares.

As snap-on abrem-se e fecham-se com os dedos, não requerem ferramentas, e são completamente reutilizáveis.

**Nota:** Muitas antenas comerciais do tipo quad não têm choke e funcionam perfeitamente. O quad tem uma geometria intrinsecamente bem equilibrada no feedpoint. O choke serve principalmente para obter medições fiáveis durante o ajuste, não é um requisito para uso normal.

<p align="center">
  Detalhe da soldadura do driven
  Driven element com coaxial e selagem
</p>

### 4.3. Procedimento de ajuste
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

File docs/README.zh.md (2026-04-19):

# OpenQuad —— 模块化可折叠 Cubical Quad（立方四方天线）

**作者 EA4IPW —— 实例：为 435 MHz 构建 5 单元 quad 天线**

<p align="center">
  设计示意图
</p>

---

## 1. 本设计是什么

本项目记录了一种**模块化可折叠 Cubical Quad 天线设计**，其构想是使用 3D 打印件、玻璃纤维或木棒作为撑杆，以及 PVC、木材或铝合金主梁来制作。

本设计的主要特点如下：

- **模块化：** 每个元件（反射器、驱动元、引向器）都安装在独立的*模块*上，该模块可在主梁上滑动并固定。你可以使用相同的硬件构建 2、3、5、6、7…… 单元的天线。
- **可折叠：** 撑杆可围绕模块枢转，因此天线可折拢用于运输或存放，并能在几秒钟内展开投入使用。
- **按频段可扩展：** 基于 OpenSCAD 的参数化设计（[src/all_in_one.scad](../src/all_in_one.scad)）允许调整主梁与撑杆的直径，并为其他主梁与撑杆尺寸重新生成零件。

- **可调：** 环形单元由 3D 打印夹子（[stls/regular_wire_clamp.stl](../stls/regular_wire_clamp.stl)）固定，可在调谐过程中修剪并重新固定导线。

本指南记录了实际建造与调谐的逐步过程。理论基础（1005/1030/975 公式的来源、velocity factor 的影响、预期性能、参考文献）在另一份文档中论述：

> 📘 **[TEORIA.zh.md](TEORIA.zh.md) —— 理论基础与参考文献**

这些公式对任何频率都适用；作为详细的实例，本文记录了针对 70 cm 频段（435 MHz）、使用 0.5 mm² PVC 安装导线的真实制作过程。

<p align="center">
  展开的天线（5 单元，435 MHz）
  折叠后便于运输的天线
</p>

---
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

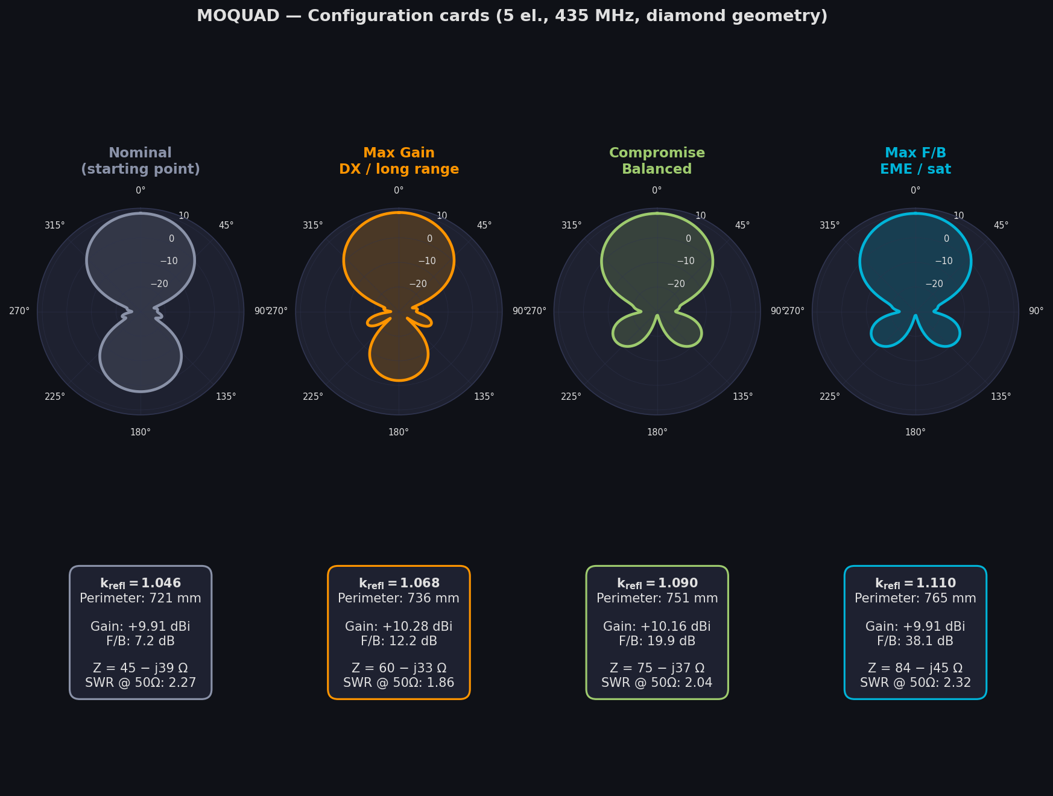
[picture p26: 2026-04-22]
docs/images/gallery/en/08_design_summary.png

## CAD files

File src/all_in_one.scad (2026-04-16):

// All-in-One Antenna Hub - v6
// 4x antenna boom clamps arranged around a central boom collar
// Print-in-place assembly with configurable gaps
// EA4IPW - Parametric design
//
// Change spreaders_dia or boom_dia and everything scales:
// clamp body, collar, pivot holes, plate spacing, base plate.

// ============================================================
// FREE PARAMETERS (the only things you should normally change)
// ============================================================

/* [Boom] */
boom_is_round = true;
boom_dia = 15.9;            // Main boom tube diameter
boom_side = 15.1;           // Main boom tube side (square boom)
spreaders_dia = 8.10;       // Wire spreaders diameter

// ============================================================
// DESIGN CONSTANTS (structural/hardware, rarely changed)
// Hidden from the customizer — edit here in source if needed.
// ============================================================

// Print-in-Place
/* [Hidden] */
print_gap = 0.20;           // Z-axis gap between parts (critical for print-in-place)
clamp_collar_gap = 0.85;    // Radial gap between collar and clamp front

// Clamp Constants
/* [Hidden] */
clamp_wall = 3;              // Wall thickness around boom in clamp
clamp_width_extra = 0.35;    // Extra wall per side on width (M3 hardware clearance)
clamp_fillet_r = 2;          // Clamp edge rounding
clamp_body_length = 25;      // Clamp total length (Y axis)
ear_drop = 3;                // Clamp ear extension below body (M3 hardware, fixed)
ear_length = 10;             // Clamp ear Y extent

// Main Body Constants
/* [Hidden] */
fillet_r = 0.5;              // Main body fillet radius
boom_around = 3;             // Collar total growth beyond boom (wall = boom_around/2 per side)
body_height = 2.3;           // Base plate thickness
bs_holder_thickness = 1.5;   // Pivot frame plate thickness
collar_above_clamp = 3.3;    // Collar extends this far above clamp attachment
base_plate_margin = 2.2;     // Base plate extends beyond clamp attachment point

// Pivot Constants
/* [Hidden] */
pivot_d = 3.6;               // Pivot cylinder diameter (on clamp)
pivot_clearance = 0.7;       // Radial clearance around pivot in hole

// Lock Detent Constants
/* [Hidden] */
lock_bump_dia = 4.0;            // Diameter of locking bump sphere
lock_bump_protrusion = 1.5;     // How far bump extends beyond clamp body surface
lock_radius = 6;                // Distance from pivot center to bump center
lock_angle_open = 75;           // Angle at open (print) position (degrees)
lock_indent_dia = 4.5;          // Indent sphere diameter (slightly larger than bump for clearance)
lock_indent_depth = 1.8;        // Indent depth into plate

// Quality
/* [Hidden] */
$fn = 80;

// ============================================================
// DERIVED (calculated from free params + constants)
// Never set these manually — change the inputs above instead.
// ============================================================

// --- Boom dimension (replaces boom_dia_eff) ---
boom_dim = boom_is_round ? boom_dia : boom_side;

// --- Square collar around main boom ---
collar_side = boom_dim + boom_around;

// --- Clamp body dimensions (scale with spreaders_dia) ---
clamp_body_height = spreaders_dia + 2 * clamp_wall;
clamp_body_width  = spreaders_dia + 2 * (clamp_wall + clamp_width_extra);

// --- Collar and pivot frame height ---
boom_around_h = fillet_r + print_gap + clamp_body_height + collar_above_clamp;
bs_holder_height = boom_around_h;

// --- Pivot frame plate width (maintains print_gap to clamp body) ---
bs_holder_width = clamp_body_width + 2 * print_gap;

// --- Clamp placement offsets ---
clamp_z_offset = body_height + fillet_r + print_gap + clamp_body_height;
clamp_y_offset = collar_side / 2 + clamp_collar_gap;

// --- Base plate diameter ---
body_side = 2 * (clamp_y_offset + clamp_body_length/2 + base_plate_margin);

// --- Pivot hole in pivot frame (derived from clamp placement + pivot geometry) ---
pivot_hole_dia  = pivot_d + 2 * pivot_clearance;
// Pivot Y/Z in absolute coords, then made relative to bs_holder origin
pivot_hole_h    = clamp_z_offset - pivot_d/2 - body_height;
pivot_hole_dist = pivot_d/2 + clamp_y_offset;

// --- Lock detent positions ---
// Bump position in clamp local frame (pivot center at pivot_d/2, pivot_d/2)
lock_y_open = pivot_d/2 + lock_radius * cos(lock_angle_open);
lock_z_open = pivot_d/2 + lock_radius * sin(lock_angle_open);
// 90° closed position (clamp rotated -90° in local frame = +90° physical fold-up)
lock_angle_closed = lock_angle_open - 90;
lock_y_closed = pivot_d/2 + lock_radius * cos(lock_angle_closed);
lock_z_closed = pivot_d/2 + lock_radius * sin(lock_angle_closed);
// Indent positions in arm coords (after rotate[0,180,0] + translate)
// The rotate flips Z, so z_assembly = clamp_z_offset - z_local
indent_0_y = clamp_y_offset + lock_y_open;
indent_0_z = clamp_z_offset - lock_z_open;
indent_90_y = clamp_y_offset + lock_y_closed;
indent_90_z = clamp_z_offset - lock_z_closed;

// ============================================================
// MODULES
// ============================================================

module _body() {
    cs_raw = collar_side - 2*fillet_r;
    union() {
        // Base plate (circular)
        cylinder(d=body_side - 2*fillet_r, h=body_height - fillet_r);
        // Collar (square prism, centered) — more material at corners
        translate([-cs_raw/2, -cs_raw/2, 0])
            cube([cs_raw, cs_raw, body_height + boom_around_h - fillet_r*2]);
    }
}

module body() {
    translate([0, 0, fillet_r])
        minkowski() {
            _body();
            sphere(r = fillet_r);
        }
}

module boom_hole() {
    if (boom_is_round) {
        cylinder(h=boom_around_h + body_height + fillet_r, d=boom_dia);
    } else {
        // Square boom hole through the square collar
        translate([0, 0, (boom_around_h + body_height) / 2])
            cube([boom_side, boom_side, (boom_around_h + body_height) * 3], center=true);
    }
}

module bs_holder() {
    // Pivot frame: two vertical plates that straddle the clamp body.
    // Plates start from center (y=0) and extend to base plate edge.
    // The collar and boom_hole handle the inner portions.
    translate([-bs_holder_thickness/2, 0, body_height])
    difference() {
        union() {
            eff_width = bs_holder_width + fillet_r*2;
            eff_depth = body_side / 2;
            // Left plate
            translate([-eff_width/2 - bs_holder_thickness/2, 0, 0])
                cube([bs_holder_thickness, eff_depth, bs_holder_height - fillet_r]);
            // Right plate
            translate([+eff_width/2 + bs_holder_thickness/2, 0, 0])
                cube([bs_holder_thickness, eff_depth, bs_holder_height - fillet_r]);
        }
        // Pivot hole — aligns with clamp pivot cylinders
        translate([-bs_holder_width/2 - bs_holder_thickness/2 - fillet_r*2, pivot_hole_dist, pivot_hole_h])
            rotate([0, 90, 0])
            cylinder(d=pivot_hole_dia, h=bs_holder_width + bs_holder_thickness + fillet_r*8);
    }
}

module lock_indents() {
    // Cylindrical indents on inner face of each plate at 0° and 90° positions.
    // Cut these AFTER minkowski to get clean cavities.
    for (side = [1, -1]) {
        // Spherical indents — smooth engagement ramp, self-centering with spherical bumps.
        // Sphere center at the plate inner face so it cuts a hemisphere into the plate.
        // 0° (open/print) position
        translate([side * (bs_holder_width/2 + lock_indent_depth - lock_indent_dia/2), indent_0_y, indent_0_z])
            sphere(d=lock_indent_dia);
        // 90° (closed) position
        translate([side * (bs_holder_width/2 + lock_indent_depth - lock_indent_dia/2), indent_90_y, indent_90_z])
            sphere(d=lock_indent_dia);
    }
}

// ============================================================
// ASSEMBLY
// ============================================================

use <antenna_spreader_clamp.scad>
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

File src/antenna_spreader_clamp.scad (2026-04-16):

// Antenna Spreader / Wire Clamp - v5
// Clamp body for wire spreader spikes, with optional pivots for
// print-in-place assembly in all_in_one.scad
// EA4IPW - Parametric design

// ============================================================
// FREE PARAMETERS (for standalone Customizer use)
// When called from all_in_one.scad, these are overridden
// by the module arguments.
// ============================================================

/* [Type] */
near_boom_version = false; // Near-boom version adds pivots for all_in_one assembly
driven_element = false;    // Driven element: 45° wire exit holes for soldering (no horizontal wire hole)

/* [Spreader] */
spreaders_dia = 8.10;   // Wire spreader / spike diameter

// ============================================================
// DESIGN CONSTANTS (structural/hardware, rarely changed)
// Hidden from the customizer — edit here in source if needed.
// ============================================================

// Design Constants
/* [Hidden] */
clamp_wall = 3;            // Wall thickness around spreader
clamp_width_extra = 0.35;  // Extra wall per side on width (M3 clearance)
fillet_r = 2;              // Edge rounding radius
ear_drop = 3;              // Clamping ear extension below body
ear_length = 10;           // Y extent of clamping ear
ear_slot_width=0.6;        // ear slot width, don't make too wide (1mm) to avoid cracks when tightening the screw
body_length = 30;          // Y axis (front to rear)

// Wire
/* [Hidden] */
wire_dia = 4;              // Wire pass-through hole diameter (0 to disable)
wire_from_back = 5;        // Distance from back of body to wire hole center
wire_exit_angle = 35;      // Driver: angle from vertical toward the side (degrees)
wire_spread_angle = 20;    // Driver: Y-axis spread between the two exits (degrees)

// Hardware
/* [Hidden] */
slot_width = 1;            // Fixation slot width
pivot_d = 3.6;             // Pivot cylinder diameter
pivot_l = 5;               // Pivot cylinder length
pivot_angle_cut = 90;
m3nut = 6.4;
m3head = 5.7;
m3screw = 3.5;

// Lock Detent
/* [Hidden] */
lock_bump_dia = 4.0;            // Diameter of locking bump sphere
lock_bump_protrusion = 1.5;     // How far bump extends beyond body surface
lock_radius = 6;                // Distance from pivot center to bump center
lock_angle_open = 75;           // Angle at open (print) position (degrees from pivot)

// Quality
/* [Hidden] */
$fn = 80;

// ============================================================
// DERIVED (from spreaders_dia + constants)
// ============================================================
body_height = spreaders_dia + 2 * clamp_wall;
body_width  = spreaders_dia + 2 * (clamp_wall + clamp_width_extra);

// Lock bump position in clamp local frame (YZ, relative to pivot center)
lock_y_open = pivot_d/2 + lock_radius * cos(lock_angle_open);
lock_z_open = pivot_d/2 + lock_radius * sin(lock_angle_open);

// ============================================================
// MODULES
// ============================================================

module _clamp_body(body_width, body_length, body_height, fillet_r, ear_drop, ear_length) {
    union() {
        cube([
            body_width  - 2*fillet_r,
            body_length - 2*fillet_r,
            body_height - 2*fillet_r
        ]);
        // the "ear", later slotted for fixation
        translate([0, body_length - ear_length, 0])
            cube([body_width - 2*fillet_r, ear_length - fillet_r*2, body_height - 2*fillet_r + ear_drop]);
    }
}

module clamp_body(body_width, body_length, body_height, fillet_r, ear_drop, ear_length) {
    translate([-body_width/2 + fillet_r, fillet_r, fillet_r])
        minkowski() {
            _clamp_body(body_width, body_length, body_height, fillet_r, ear_drop, ear_length);
            sphere(r = fillet_r);
        }
}

module clamp_spreader_hole(body_height, body_length, spreader_dia, ear_drop, fillet_r) {
    // Horizontal hole for wire spreader, through the body center
    translate([0, 5, body_height/2])
        rotate([90, 0, 180])
        cylinder(d=spreader_dia, h=body_height + ear_drop + 40);
}

module clamp_spreader_hole_insert(body_length, body_height, spreader_dia) {
    // Chamfered entry for spreader insertion
    translate([0, body_length, body_height/2])
        rotate([90, 0, 0])
        cylinder(d1=spreader_dia+1, d2=spreader_dia, h=1);
}

module wire_hole(body_width, body_length, body_height, wire_dia, wire_from_back, slot_width, driven_element) {
    if (wire_dia > 0) {
        if (driven_element) {
            // Driver element: angled holes on each side of the slot.
            // Each hole starts above spreader center, angles outward (±X)
            // and downward (-Z) for pulling wires out for soldering.
            // wire_exit_angle: 0=straight down, 90=horizontal
            // wire_spread_angle: Y-axis spread between the two exits
            for (side = [1, -1]) {
                translate([0, wire_from_back * 2, -body_height*0.2])
                    rotate([0, 0, side < 0 ? 180 : 0])
                    rotate([side < 0 ? -wire_spread_angle : wire_spread_angle,
                            wire_exit_angle, 0])
                    cylinder(d=wire_dia, h=body_width * 2, center=false);
            }
        } else {
            // Regular element: horizontal wire pass-through + vertical exit holes
            translate([0, wire_from_back, body_height/2])
                rotate([0, 90, 0])
                cylinder(d=wire_dia, h=body_width + 20, center=true);
        }
    }
}

module fixation_slot(slot_width, body_length, body_height) {
    translate([-slot_width/2, 0, body_height/2])
        cube([slot_width, body_length, 20]);
}

module nut_hole(body_width, body_length, body_height) {
    translate([-10, body_length-5, body_height-0.5])
        rotate([0, 90, 0])
        union() {
            cylinder(d=m3nut, h=6, $fn=6);
            cylinder(d=m3screw, h=body_width*2);
            translate([0, 0, body_width-1])
                cylinder(d=m3head, h=5);
        }
}

module pivot(fillet_r) {
    difference() {
        translate([-fillet_r, pivot_d/2, pivot_d/2])
            rotate([0, 90, 0])
            cylinder(d=pivot_d, h=pivot_l+fillet_r);
        translate([pivot_l*0.8, pivot_d/2, pivot_d])
            rotate([0, pivot_angle_cut])
            cube([20, pivot_d, pivot_d], center=true);
    }
}

module back_bend_insert(slot_width, body_length) {
    translate([-slot_width/2, 0, 0])
        cube([slot_width, body_length/3, 20]);
}

module lock_bump(body_width, lock_y, lock_z, bump_dia, bump_protrusion) {
    // Spherical bumps on both sides of the body near the pivot.
    // The sphere center is shifted inside the body so only
    // bump_protrusion extends past the body surface.
    for (side = [1, -1]) {
        translate([side * (body_width/2 - bump_dia/2 + bump_protrusion), lock_y, lock_z])
            sphere(d=bump_dia);
    }
}

// ============================================================
// MAIN MODULE
// All parameters have defaults matching the file-level derived
// values. When called from all_in_one.scad, pass overrides.
// ============================================================
module antenna_spreader_clamp(
    near_boom_version = true,
    body_width = undef,
    body_length = 25,
    body_height = undef,
    fillet_r = 2,
    spreader_dia = 8.10,
    ear_drop = 3,
    ear_length = 10,
    lock_y = undef,
    lock_z = undef,
    lock_d = 4.0,
    lock_p = 1.5
) {
    // undef params fall back to file-level derived values for standalone use.
    _bw = (body_width == undef)  ? spreader_dia + 2*(clamp_wall + clamp_width_extra) : body_width;
    _bh = (body_height == undef) ? spreader_dia + 2*clamp_wall : body_height;
    _ly = (lock_y == undef) ? lock_y_open : lock_y;
    _lz = (lock_z == undef) ? lock_z_open : lock_z;

    difference() {
        union() {
            clamp_body(_bw, body_length, _bh, fillet_r, ear_drop, ear_length);
            // Near-boom version adds pivots + lock bumps for all_in_one assembly
            if (near_boom_version) {
                translate([_bw/2, 0, 0]) pivot(fillet_r);
                translate([0, pivot_d, 0])
                    rotate([0, 0, 180])
                    translate([_bw/2, 0, 0]) pivot(fillet_r);
                // Detent bumps on both sides for snap-fit locking
                lock_bump(_bw, _ly, _lz, lock_d, lock_p);
            }
        }
        clamp_spreader_hole(_bh, body_length, spreader_dia, ear_drop, fillet_r);
        clamp_spreader_hole_insert(body_length, _bh, spreader_dia);
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

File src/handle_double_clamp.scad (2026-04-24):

// Handle Double-Tube Clamp - v1
// Two-half clamp that grips two parallel round tubes and exposes a
// solid square male plug (7.99 mm sq, 17.6 mm long) that inserts into
// the mast/handle boom_segment's female socket (see non_foldable_quad.scad).
// EA4IPW - Parametric design
//
// Hardware: 2x M3x10 screws + hex nuts. Heads recess into the bottom
// half (from the outer -Z face), nuts sit in pockets on the top half
// (from the outer +Z face, alongside the plug). Screws sit in the
// midline between the two tubes, flanking the plug. 5mm-deep recesses
// on each side leave 10mm of material between them to match the M3x10
// shaft length.

// ============================================================
// FREE PARAMETERS
// ============================================================

/* [Render] */
render_part    = "both";   // "top", "bottom", or "both" (print plate)

/* [Tubes] */
tube_dia       = 13.4;     // Clamped tube outer diameter
tube_spacing   = 40.0;     // Center-to-center between the two tubes
tube_clearance = 0.10;     // Added to bore diameter; M3s close the rest

/* [Body] */
clamp_length   = 28.0;     // Along tube axis (Y)
wall           = 5.0;      // Material around each tube bore
end_margin     = 5.0;      // Material from tube outer surface to body X-end

// ============================================================
// DESIGN CONSTANTS (hardware / printability)
// ============================================================

/* [Hidden] */
boom_dia          = 8.0;   // Mirrors non_foldable_quad.scad
print_gap         = 0.01;  // Press-fit clearance (same convention)
hub_wall          = 3;     // Wall around the socket (matches boom_segment)
socket_depth      = 14;    // Depth of the blind square socket
fillet_r          = 2;     // Minkowski sphere radius for rounded body
m3screw           = 3.5;   // M3 clearance hole
m3head            = 5.7;   // M3 socket-head cap diameter
m3nut             = 6.4;   // M3 hex nut across-corners (pocket dia)
// M3x10 screw budget: head (~3mm) + 10mm under-head length.
// Recesses sized so head-bottom and nut-top leave exactly 10mm of
// material between them, matching the screw's under-head length:
//   body_height (20) - head_recess (5) - nut_pocket (5) = 10 mm.
nut_pocket_depth  = 8.0;
head_recess_depth = 8.0;
screw_edge        = 5.0;   // Y distance from body end to screw center
eps               = 0.01;  // Overcut for clean boolean cuts

/* [Hidden] */
$fn = 80;

// ============================================================
// DERIVED
// ============================================================

bore_dia    = tube_dia + tube_clearance;
body_height = tube_dia + 2 * wall;
body_width  = tube_spacing + tube_dia + 2 * end_margin;
half_h      = body_height / 2;

// Solid male plug that slots into the handle boom_segment's female
// socket. Matches the plug geometry from non_foldable_quad.scad.
plug_side   = boom_dia - print_gap;          // 7.99 mm
plug_len    = 17.6;                          // Matches non_foldable_quad.scad

// Screws sit in the midline between the tubes (Y=0), flanking the
// handle socket that comes out of the +Y face at X=0. Offset along X
// must clear both the socket (soc/2 + head radius) and the tube bores.
screw_x_offset = 8.0;
screw_xs       = [-screw_x_offset, +screw_x_offset];
screw_ys       = [0];

// ============================================================
// MODULES
// ============================================================

// Rounded rectangular body, centered at origin, spanning
// [-body_width/2, +body_width/2] x [-clamp_length/2, +clamp_length/2] x
// [-body_height/2, +body_height/2]. Minkowski keeps outer dims exact.
module _rounded_body() {
    inner_x = body_width   - 2 * fillet_r;
    inner_y = clamp_length - 2 * fillet_r;
    inner_z = body_height  - 2 * fillet_r;
    minkowski() {
        cube([inner_x, inner_y, inner_z], center = true);
        sphere(r = fillet_r);
    }
}

// Solid square plug on +Z, centered at X=Y=0 between the two screw
// holes. Axis along Z. Base sinks into the top half's body for a
// clean union; tip extends past the body's top face.
// plug_embed: how much of the plug lies inside the body (gives it a
// structural root into the top half). plug_len total, so the part
// sticking out past the +Z face = plug_len - plug_embed.
module _tip_plug() {
    plug_embed = 1;  // Stays within top half, leaves 1 mm floor
    z_base = half_h - plug_embed;
    translate([-plug_side/2, -plug_side/2, z_base])
        cube([plug_side, plug_side, plug_len]);
}

module _body_solid() {
    union() {
        _rounded_body();
        _tip_plug();
    }
}

// Two tube bores along Y through the body. Cut is slightly longer than
// the clamp so the faces stay clean after Minkowski.
module _tube_bores() {
    for (sx = [-1, +1])
        translate([sx * tube_spacing/2, 0, 0])
            rotate([90, 0, 0])
                cylinder(
                    d = bore_dia,
                    h = clamp_length + 2 * fillet_r + 2 * eps,
                    center = true
                );
}

// Vertical through-clearance for each M3 screw.
module _screw_clearance() {
    for (x = screw_xs, y = screw_ys)
        translate([x, y, 0])
            cylinder(
                d = m3screw,
                h = body_height + 2 * fillet_r + 2 * eps,
                center = true
            );
}

// Hex nut pockets, sunk from the +Z face of the top half. The plug
// sticks out of the same face but is offset in X, so no collision.
// $fn=6 -> hexagonal cross section. Diameter is across-corners.
module _nut_pockets() {
    for (x = screw_xs, y = screw_ys)
        translate([x, y, body_height/2 - nut_pocket_depth])
            cylinder(d = m3nut, h = nut_pocket_depth + eps, $fn = 6);
}

// Cylindrical head recesses, sunk from the -Z face of the bottom half.
module _head_recesses() {
    for (x = screw_xs, y = screw_ys)
        translate([x, y, -body_height/2 - eps])
            cylinder(d = m3head, h = head_recess_depth + eps);
}

// Full undivided part with all cuts applied except the half-space split.
// "which" = "top" or "bottom" so we only add that half's hardware pocket.
module _clamp_with_cuts(which) {
    difference() {
        _body_solid();
        _tube_bores();
        _screw_clearance();
        if (which == "bottom") _head_recesses();
        if (which == "top")    _nut_pockets();
    }
}

// One half, split at Z=0 through the tube centers. Top = Z>=0, bottom = Z<=0.
module half(which) {
    assert(which == "top" || which == "bottom",
        str("half() which must be \"top\" or \"bottom\", got: ", which));
    // Use a large cutter box aligned on the split plane.
    box = max(body_width, clamp_length + plug_len, body_height) * 2;
    intersection() {
        _clamp_with_cuts(which);
        if (which == "top")
            translate([0, 0, box/2]) cube(box, center = true);
        else
            translate([0, 0, -box/2]) cube(box, center = true);
    }
}
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

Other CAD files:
src/non_foldable_quad.scad

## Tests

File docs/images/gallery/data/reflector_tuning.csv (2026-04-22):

k_refl | perim_mm | gain_dBi | fb_dB | R_ohm | X_ohm | swr_50
1.02 | 703.0 | 8.51 | 3.1 | 36.23 | -53.95 | 3.419
1.022 | 704.3 | 8.64 | 3.4 | 36.48 | -52.84 | 3.331
1.024 | 705.7 | 8.77 | 3.6 | 36.79 | -51.71 | 3.24
1.026 | 707.1 | 8.9 | 3.9 | 37.15 | -50.57 | 3.148
1.028 | 708.5 | 9.02 | 4.2 | 37.58 | -49.42 | 3.054
1.03 | 709.9 | 9.14 | 4.5 | 38.08 | -48.26 | 2.96
1.032 | 711.2 | 9.26 | 4.8 | 38.65 | -47.1 | 2.866
1.034 | 712.6 | 9.37 | 5.1 | 39.28 | -45.95 | 2.773
1.036 | 714.0 | 9.48 | 5.4 | 39.99 | -44.8 | 2.681
1.038 | 715.4 | 9.58 | 5.7 | 40.78 | -43.68 | 2.592
1.04 | 716.7 | 9.67 | 6.1 | 41.64 | -42.57 | 2.505
1.042 | 718.1 | 9.76 | 6.4 | 42.57 | -41.5 | 2.422
1.044 | 719.5 | 9.84 | 6.8 | 43.58 | -40.46 | 2.344
1.046 | 720.9 | 9.91 | 7.2 | 44.66 | -39.46 | 2.27
1.048 | 722.3 | 9.98 | 7.6 | 45.8 | -38.52 | 2.201
1.05 | 723.6 | 10.03 | 8.0 | 47.02 | -37.63 | 2.139
1.052 | 725.0 | 10.09 | 8.4 | 48.3 | -36.8 | 2.082
1.054 | 726.4 | 10.13 | 8.8 | 49.63 | -36.05 | 2.032
1.056 | 727.8 | 10.17 | 9.3 | 51.02 | -35.37 | 1.988
1.058 | 729.2 | 10.2 | 9.7 | 52.45 | -34.77 | 1.951
1.06 | 730.5 | 10.23 | 10.2 | 53.92 | -34.26 | 1.92
1.062 | 731.9 | 10.25 | 10.7 | 55.42 | -33.83 | 1.896
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

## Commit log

2026-04-11 reorg: sanitized parameters and imports from all_in_one
    [all_in_one.scad, antenna_boom_clamp.scad]
2026-04-11 reorganize parameters a bit more
    [all_in_one.scad, antenna_boom_clamp.scad]
2026-04-11 square collar for main boom, and better nut positioning
    [all_in_one.scad, antenna_boom_clamp.scad]
2026-04-11 locking protrusions
    [all_in_one.scad, antenna_boom_clamp.scad]
2026-04-11 fix parameter passing to standalone clamp
    [all_in_one.scad, antenna_boom_clamp.scad]
2026-04-11 driver holes
    [antenna_boom_clamp.scad]
2026-04-13 various fixes
    * Reduced slot on ear, to avoid cracking when tightening screws.
    * Better angle for driven element wire
    [antenna_boom_clamp.scad]
2026-04-15 organizing files
    [all_in_one.scad, antenna_boom_clamp.scad]
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2026-04-15 Add EGL/GL runtime libs needed by OpenSCAD AppImage
    [antenna_spreader_clamp.scad]
2026-04-15 Rename boom clamp to spreader clamp; fix driver/driven typo
    - Rename src/antenna_boom_clamp.scad to src/antenna_spreader_clamp.scad
    and update all boom references within it to spreader (keeping
    near_boom_version as the one intentional boom reference).
    - Fix "driver_element" -> "driven_element" throughout.
    - Link Spanish and English guides from README.md; add README.es.md.
    [all_in_one.scad, antenna_spreader_clamp.scad]
2026-04-15 Add multilingual calculator, translations, and docs/ folder
    - Web calculator (web/index.html) for cubical quad sizing with i18n
    (es/en/it/pt/ja/zh), Vf calibration from measured frequency,
    theoretical gain and F/B stats, and per-element trim recommendations
    - GitHub Pages deploy workflow (.github/workflows/deploy-pages.yml)
    publishing the calculator from web/
    - README.md converted into a multilingual hub
    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
2026-04-15 Add prominent GitHub backlink and fix repo URLs
    The hardcoded URLs pointed at the placeholder EA4IPW/cubic_quad_modular
    repo. Updated to mangelajo/openquad-antenna everywhere (constants in JS,
    fallback HTML, and TEORIA cross-link). Added a GitHub button with the
    Octocat mark in the topbar next to the language selector so users on
    the Pages site can jump to the source.
2026-04-16 Upload STL artifacts to GitHub releases
    Trigger the build workflow on release publish events and attach
    the built STL files to the release using gh CLI.
2026-04-16 Add Makefile for local STL builds and use it in CI
    Codifies the three OpenSCAD render commands so contributors can run
    `make` locally instead of copying steps out of the workflow. The CI job
    now invokes the same Makefile, passing OPENSCAD="xvfb-run -a openscad"
    to keep its headless Linux setup.
2026-04-16 Add parameter-matrix STL builds, per-combo zips, and scad cleanup
    Sweeps boom shape (round/square) × boom dim (14.9, 15.9, 19.9 mm) ×
    spreader dim (8.10, 4.05, 6.07 mm) into 18 combo directories under
    build/, with each STL prefixed by {r|s}_b{bd}_s{sd}_ for traceability,
    and a flat per-combo zip alongside. CI now builds the matrix in
    parallel (-j4) and uploads the zips as both a workflow artifact and to
    releases.
    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
    [all_in_one.scad, antenna_spreader_clamp.scad]
2026-04-16 Render PNG previews and bundle them in matrix zips
    Adds 'renders' make target that produces 800x800 PNGs at a 45/45
    view (clock/F6 quality, manifold backend) for the 3 default STLs and
    all 54 matrix STLs, with ClearSky as the default colorscheme.
    Per-combination zips now depend on the corresponding PNGs and include
    both the STL and PNG files, so CI's existing 'make -j4 zip' step ships
    previews alongside the printable parts. Adds a self-documenting 'help'
    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
2026-04-16 Add docs-images target and pre-built parts gallery
    New 'docs-images' make target renders the 54 matrix PNGs and copies
    them to docs/images/generated/, so the README gallery can be
    regenerated from the OpenSCAD sources at any time. README.en.md gains
    a "Pre-built parts" section with a 6×3 all-in-one preview matrix, a
    spreader-clamp variants table, and a download grid that pulls the
    per-combination zips from the latest GitHub release.
2026-04-16 Tweak render camera angle to a higher 3/4 view
    Camera rotation switched to (65, 0, -135) — slightly higher tilt and
    the opposite spin around the boom axis. Regenerates all 54 docs/
    preview PNGs so the README gallery stays in sync with what CI ships in
    the release zips.
2026-04-16 Document custom-size workflow and pivot pre-check warning
    Adds README § 7.4 covering both rendering paths for builders whose
    boom or spreader sizes aren't in the pre-rendered matrix: an OpenSCAD
    GUI walkthrough (customizer + F6 + export) and a CLI/Makefile
    walkthrough (edit-and-make, plus copy-pasteable openscad -D
    invocations). A prominent callout warns users to visually inspect the
    print-in-place pivots and lock detents before slicing, since unusual
    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
2026-04-16 Translate pre-built parts gallery to es/it/pt/ja/zh READMEs
    Mirrors the new § 7 (preview matrix, spreader-clamp variants, download
    grid, custom-size workflow with pivot pre-check warning, OpenSCAD GUI
    + CLI walkthroughs) into the Spanish, Italian, Portuguese, Japanese
    and Chinese READMEs. Image filenames and release-zip URLs are
    language-agnostic and shared with the English version.
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2026-04-18 Add materials summary table and online calculator links to README.es
    - Insert consolidated materials table at the start of section 3
    (cable, boom, spreaders, fasteners, coaxial, heat-shrink, ferrites)
    - Link https://openquad-calc.ea4ipw.es in §2 and §4.3 step 1
    - Rewrite Vf procedure to recommend building with Vf=1, measuring
    the full antenna, and correcting dimensions via the calculator
    - Broaden §1 materials mention to include wood spreaders and
    PVC/wood booms
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2026-04-18 Propagate README.es additions (fbb23db) to en/it/pt/ja/zh
    Mirrors the four changes from commit fbb23db to the five non-Spanish
    README translations:
    - Insert consolidated materials summary table at the start of §3
    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
2026-04-19 Rewrite physics in SI-direct form with Vf=0.99 default
    Replace the historical 1005/f ft·MHz constant with λ = c/f directly in
    mm and k × λ × Vf, so every formula is traceable to SI units. Document
    that bare copper in air has Vf ≈ 0.97–0.99 (not exactly 1.0), and set
    0.99 as the recommended starting value. Keep §1.4 equivalence with
    1005/f for readers familiar with the ARRL convention.
    Only the Spanish docs are updated; en/it/pt/ja/zh propagation pending.
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2026-04-19 Propagate README.es §4.3 Step 1 rewrite to en/it/pt/ja/zh
    Align the Vf calibration procedure across all languages: replace the
    old 'skip if bare copper' branch and the 1005/f formula with the
    build-and-measure approach (start from a typical Vf for the wire,
    build, measure, recalibrate via the online calculator). References
    the new SI-direct formula perimeter = k × λ × Vf.
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2026-04-19 Propagate README.es photo gallery to en/it/pt/ja/zh
    Place the design diagram at the very top (before §1), add the
    deployed/folded hero pair at the end of §1, and mirror the
    construction photos inserted in the Spanish README throughout
    §3.1–§3.5, §4.1–§4.3, §6, and §7.1 with translated alt text. Also
    adds the cable-splicing paragraph in §3.1 that was missing in
    en/it/pt/ja/zh.
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2026-04-19 non foldable quad
    [non_foldable_quad.scad]
2026-04-20 Non foldable design
    [non_foldable_quad.scad]
2026-04-22 Improve non-foldable with driven holes and labels
    [non_foldable_quad.scad]
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2026-04-22 docs(teoria): expand §5 references with quad/Yagi sources
    - Replace the YT1VP calculator entry with a technical note that
    spells out its 730 ft·MHz / 600 ft·MHz spacing constants and
    cross-references §1.6.
    - Rewrite "Artículos online" with direct links to Cebik (W4RNL)
    volumes, the W8JI quad page (with its gain/F/B tradeoff quote),
    Wikipedia's Yagi–Uda mutual-impedance section, KD2BD's matching
    article, and the Electronics Notes feed-impedance page.
    - Add a new "Libros recomendados" subsection (Lawson W2PV, Orr
    W6SAI, Leeson, ARRL Antenna Book).
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2026-04-22 docs: add multi-language NEC2 plot gallery (24 PNGs, 6 langs)
    Runs tools/nec2_spacing_analysis.py --full-data-dump to produce four
    CSVs under docs/images/gallery/data/, then renders four plots per
    language (es/en/it/pt/ja/zh) with tools/nec2_plot_gallery.py.
    Two small fixes baked in:
    - nec2c has a hard-coded 80-char limit on the input/output filename
    (misc.c, abort_on_error(-1)). On macOS, Python's mkdtemp() path
    already eats ~60 chars, leaving no room for our per-run file names
    and causing all runs to abort. When --full-data-dump is set and no
    explicit --workdir was given, reuse the dump directory itself as
    the workdir — a relative path that stays well under the limit.
    - Hira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
    [impedance_sweep.csv, patterns.csv, reflector_tuning.csv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]
2026-04-24 feat(src): add handle_double_clamp parametric part
    Two-half clamp that grips two parallel round tubes and exposes a
    square male plug mating with non_foldable_quad's boom_segment socket.
    2x M3x10 hardware; printable as top, bottom, or both.
    [handle_double_clamp.scad]
